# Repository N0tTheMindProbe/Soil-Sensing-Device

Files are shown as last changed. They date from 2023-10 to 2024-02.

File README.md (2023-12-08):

**Overview** 

Welcome to Twin Cities Engineering’s soil gas sensing project. Here, you will find full documentation for both the hardware and software components of our newly developed soil gas sensing device. 

Soil health is a key part within the realm of agriculture and environmental sustainability. As such, understanding the composition of gases within soil void spaces is a powerful means to monitor soil health, offering crucial insights into nutrient content and microorganism activity. Unfortunately, existing commercial soil gas measurement devices are prohibitively expensive, limiting access for farmers and soil scientists alike. To bridge this gap, our team of student engineers is crafting an affordable DIY soil gas sensing device designed to measure carbon dioxide concentrations at three distinct soil depths every 2-3 hours. Our goal is to create a prototype that is not only economical but also portable and user-friendly, increasing accessibility to those wishing to measure and track soil health. 

Our prototype works by collecting gas samples from soil void spaces. This is accomplished with three soil probes of varying lengths (10cm, 20cm, and 50cm) positioned at each of the aforementioned depths. A pump and solenoid valves are used to collect gas samples sequentially from each depth, so they can be passed over a carbon dioxide sensor. A Mayfly microcontroller is used to control each of these functions and record the gas data collected from the sensor. This dynamic setup allows for precise monitoring and data collection, providing a cost-effective and efficient solution for soil health analysis. 

The development of the programming for this device was made possible through the utilization of resources provided by EnviroDIY's ModularSensors repository. The extensive collection of tutorials, libraries, and code documentation available in the ModularSensor repository allowed our team to streamline the programming process and ensure consistent functionality of the soil gas sensing prototype.  

**Quick Start Guide** 

The following is a quick start guide for those wishing to assemble their own soil sensing device. 

Prerequisites: 

Creating a replicated version of our soil sensing prototype does not require extensive programming expertise, making it accessible to those with minimal prior knowledge. However, having the right Integrated Development Environment (IDE) is crucial for compiling and uploading the necessary code to the microcontroller. We highly recommend using VScode with the PlatformIO extension for this purpose. The code for this device relies on numerous libraries from EnviroDIY’s ModularSensor repository, Adafruit, as well as locally sourced ones. The PlatformIO extension conveniently manages and sources all these libraries, saving individuals from having to manage all these libraries themselves. For this reason, we strongly advise using this configuration over simpler compilers like the Arduino IDE. 

Both VSCode and PlatformIO are free to install and run on both Windows and Mac. A detailed tutorial by EnviroDIY on how to download and configure these tools for our project can be found here. 

**Hardware requirements:** 

We selected the Mayfly Data Logger as the microcontroller for this project. Designed by the EnviroDIY community, the Mayfly microcontroller was specifically tailored with environmental data monitoring in mind. For additional hardware specifications and purchasing links, please refer to the EnviroDIY website. 

**Software dependencies/Installation instructions:** 

To install the software for the Mayfly controller, download the ZIP file for the project and open it using PlatformIO. With the project opened, the workstation in VSCode should look similar to this: 



In the examples folder, there are a variety of individual files for each of the main mechanisms of the sensor. These can be ignored, unless individual testing/calibration of components is required.  

To upload the code to the Mayfly device, ensure the connection between the Mayfly and the computer is secure, and that VSCode recognizes the device. Click the checkmark (PlatformIO: Build) located at the bottom left of the screen. VSCode may take several seconds to install and compile each of the libraries required for the prototype to run. Afterwards, the terminal should show a “success” message.  

Clicking the arrow button to the right of the compile checkmark will upload the code to the Mayfly device. Again, this can take up to a minute to complete. Once the code has been successfully uploaded to the Mayfly device, further testing in the Serial Monitor can be done to ensure that the prototype is working as expected. Otherwise, the Mayfly can be unplugged from the computer and installed into the device.   

**Hardware Components** 

Detailed documentation regarding complete hardware assembly (such as component lists, electrical schematics, and pin configurations for the Mayfly) will be located in the docs folder as it becomes available.  

**Software Architecture** 

The general process for the prototype’s programming is shown in the following diagram.  

Screenshot 2023-12-08 at 5 53 21 AM

There are numerous libraries referenced within the main code file that are required to operate the soil sensing device. Several libraries, such as the sensor libraries required for the gas and temperature sensors, are sourced from EnviroDIY’s ModularSensors. There are also a few local libraries, such as the “CollectSample.h”, which is required for operating the pump and solenoids to collect gas samples from the correct depths. All of these libraries work together in the main programming code to effectively operate the prototype.  

**Calibration Procedures for the Alphasense IRC-A1 Sensor** 

The Alphasense IRC-A1 sensor is the sensor utilized in this prototype for collecting carbon dioxide readings from the soil. This sensor comes pre-calibrated by the manufacturer and are generally ready for use immediately after purchase.  

The manufacturers recommend recalibrating the sensor no less than every 12 months to maintain the highest level of accuracy. Further information on sensor calibration procedures can be found on Alphasense’s website.   

**Troubleshooting** 

Output is “nullnullnull...” 

-Adjust the monitor_speed set in the platform.io file 

-Ensure the connection between the Mayfly and computer is secure (no faults in the cable, etc.) 

Output is coming at –9999 or Device only outputs –1250ppm or Readings are very low and/or negative: 

-Ensure that connection between Mayfly and sensor is correct 

-Ensure enough power is being fed to the CO2 sensor (It needs a minimum of 12 volts) 

-If the above solutions do not amend the issue, unplug the CO2 sensor from power for at least 30 seconds, and then plug it back in.  

“Avrdude” connection error: 

-Restart your computer/VSCode workstation.  

-Ensure the USB-C cord is undamaged.   

**License**  

Our soil sensing device project is released under the BSD 3-Clause License, a permissive open-source license that allows for the redistribution and modification of the source and binary forms of the software. This license provides flexibility for users to adapt and incorporate our technology into various applications, both commercial and non-commercial, while still maintaining certain conditions such as attribution and the inclusion of the original license terms. The BSD 3-Clause License aligns with our commitment to fostering collaboration and innovation in the field of soil sensing. 

**Third-Party Licenses** 

In the development of our project, we have incorporated specific third-party libraries, each governed by its respective license. These third-party components contribute essential functionality to our soil sensing device. We adhere to the terms and conditions outlined in the licenses of these libraries or components, and users are encouraged to review the individual licenses for detailed information. This transparent approach ensures that our project not only benefits from external contributions but also upholds the principles of open collaboration and proper attribution within the broader open-source community. 

**Acknowledgments** 

We would like to extend gratitude to the EnviroDIY community for their invaluable resources that have been instrumental to our team's success throughout the semester. The utilization of the ModularSensors repository proved to be vital for creating the programming for this project, serving as a vital resource that significantly contributed to our accomplishments. 

We would also like to thank Anthony Aufdenkampe for his guidance and the contributions he provided for this project. 

EnviroDIY’s ModularSensors libraries are provided “as-is” under the BSD-3 license. Full licensing/terms of use details can be found in the ModularSensors repository here.

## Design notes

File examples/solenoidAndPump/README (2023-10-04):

This is the code that isolates the solenoid values and pump processes.

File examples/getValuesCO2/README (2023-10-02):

#this is the isolated code for the CO2 Sensor's functionality

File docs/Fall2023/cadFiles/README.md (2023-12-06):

#3D print files created by the Fall 2023 team

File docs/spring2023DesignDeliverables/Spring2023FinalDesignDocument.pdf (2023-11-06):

Final Design Document

Twin Cities Engineering

Project Team Students: David Schaeppi, Samuel Day, Kevin Lee, Brendan Dykes, and Jeodaun Lee

Spring 2023 Semester

May 5th, 2023

## Contents

## Introduction

A revolution of farmers interested in smart regenerative agricultural practices has blossomed over recent years. Many farmers of these communities are actively seeking stem tools to help monitor soil health and provide feedback to farmers on the quality of their practice. One method to measure soil health is to measure the gases within the soil. Measuring certain gases in soil provides information about the nutrients and microorganism activity within the soil. Commercially available soil pore space gas instruments are costly, with the cheapest systems costing around $100,000. The high costs leave a demand for a low budget system capable of extracting, measuring, and reporting soil gas concentrations.

To address this issue, a team of engineering students from Twin Cities Engineering at the University of Minnesota, Mankato, is planning to develop a low-cost DIY soil sensing unit. The unit will be designed to extract soil gases from four different depths, providing farmers with valuable information about their soil health. The team plans to make all the information about the project available on GitHub, an open-source platform for software development, so that other farmers and researchers can benefit from their work. By developing a low-cost soil sensing unit, the team hopes to make it easier for farmers to adopt smart regenerative agricultural practices and improve the sustainability of their farming operations.

The DIY soil sensing unit will consist of a gas sampling chamber, a vacuum pump, and an electronic sensor for detecting the gases. The team plans to use off-the-shelf components wherever possible to keep the costs low. They are also exploring the use of 3D printing technology to produce some of the components. The device will be powered by a rechargeable battery, which will be recharged with solar power, making it easy to use in the field.

In addition to providing farmers with information about their soil health, the team hopes that their project will also help to raise awareness about the importance of soil health and the role of regenerative agricultural practices in promoting sustainable agriculture. By sharing their work on GitHub, they aim to inspire others to develop similar low-cost solutions and contribute to the growing community of farmers interested in regenerative agriculture.

Current State of the Art

There are a few longstanding methods of acquiring this data from under the soil, one being gas chromatography. This is done in a large lab space where samples of the trapped gas or soil sample are brough to the lab and examined in these large machines. The chromatography machine is, bulky, high-energy cost and high dollar cost. The next champion in this segment is the FTIR.

Fourier Transform Infrared (FTIR) spectroscopy is a powerful analytical technique that can be used to analyze the composition of specific gases in soil vapor. The technique involves measuring the absorption of infrared radiation by a sample and then using this information to determine the types and amounts of molecules present in the sample.

FTIR spectroscopy works by passing infrared radiation through a sample, such as soil vapor, and measuring the amount of radiation absorbed by the sample at specific wavelengths. Different molecules absorb radiation at different wavelengths, and the resulting spectra can be used to identify the types and amounts of molecules present in the sample.

When applied to soil vapor, FTIR spectroscopy can be used to identify and quantify the concentrations of various gases, such as carbon dioxide, methane, and nitrous oxide. These gases are important indicators of soil health and can provide valuable information about soil microbial activity, nutrient cycling, and greenhouse gas emissions. So the FTIR is a force. However, this is an industry machine that costs in 100k range and requires a great deal of power. More power than we could get out of a 2ftx2ft solar array

What is the Device:

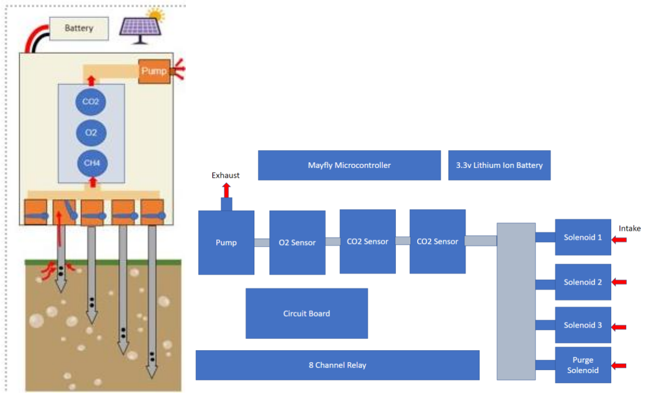
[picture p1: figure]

The images above are diagrams of the system we received from the previous team.

The Device a machine that will stay outside all growing season, it will use a solar panel to charge its batteries. It will be able to accurate a pump to draw gas from under the soil from 4 different depths, run that gas over our sensors and record the concertation of Co2, O2, and CH4. After the reading has been taken, the gas is removed from the chamber via that same pump and ejected through a port in the top of the machine. The data is then saved to an SD card as well as relevant information about Time, Date. Temperature, and Humidity.

## Project Tutorial

### Project Timeline

- Spring 2022
- Developed groundwork for entire soil sensing unit design
- Setup a pump, 8 channel relay and sensor hookup
- Fall 2022

- Created Sensor caps to connect sensors together
- Extracted readouts from sensors
- Programmed framework for device operation
- Data storage on SD card
- Eliminated solenoid noise triggering relay issue using snubbers
- Attempted to implement a methane sensor but fried it
- Spring 2023
- Created a sensor chamber included with temperature control
- Created a prototype bulk water removal system
- Fully implemented entire design into a box for total mobility
- Implemented a low-cost methane sensor
- Properly extract gas from probes
- Completed a GitHub Repository

### Device Design

Design Intent
The soil gas sensor device is designed to provide accurate and precise measurements of gas concentrations in soil. It consists of four soil probes of varying lengths (0.25, 0.5, 0.75, and 1 meter) that can be easily attached to the device. Each probe is equipped with holes to extract gas from the soil when a connected pump is activated.

To ensure accurate readings, the four probes are placed in a 1-meter squared area of soil, under the assumption that soil gas concentrations will not vary significantly within this area. The device itself has four ports to connect tubes from the probes to the device. Each port is connected to a solenoid valve inside the device, which can open and close based on the response from a Mayfly microcontroller.

To ensure precise measurements, the device allows for the exposure of one probe at a time while keeping all other valves closed. This process allows the device to accurately measure the gas concentration at each depth, providing valuable insights into the microbial activity and nutrient levels of the soil. By allowing for the measurement of gas concentrations at varying depths, farmers can make informed decisions about the timing and amount of fertilizer application, thus optimizing crop yields while reducing the use of potentially harmful fertilizers.

Behind the solenoids lies the sensor chamber. The sensor chamber houses an Alphasense IRC-AT carbon dioxide sensor, Alphasense O2-A3 oxygen sensor, a TGS2611-E00 methane sensor, a bme280 temperature, pressure, humidity sensor, and a heating element. The heating element is implemented due to our project team’s worry of condensation forming within the sensor chamber and damaging the sensors. The heating element is connected to an H-Bridge and begins heating if dew point is measured from the bme280.

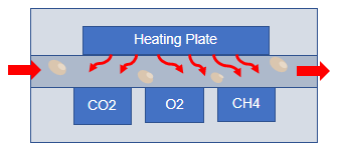
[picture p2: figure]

Figure 1

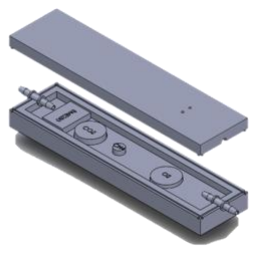
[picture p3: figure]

Figure 2

The Alphasense sensors were chosen due to professor suggestion in the reliability of the brand. Each Alphasense sensor is powered with 12V. To measure the sensors a load resistor of 230 ohms is used for both sensors. The voltage drop across the resistor is measured using an Analog Digital Converter (ADC) to read oxygen and carbon dioxide. The Alphasense IRC-AT has two signal wires. Sig+ connects to one end of the resistor while Sig- connects to the other end. The Alphasense O2-A3 however connects in series. 12 volts powers the O2-A3. The output current is an ADC measurable current of 4-20 mA. The load resistor is placed in series with the O2-A3 sensor for the ADC to measure the voltage drop.

The TGS2611-E00 was chosen due to its low cost and abundant literature claiming the sensor to be a capable low-cost sensor for methane detection. Our team lacks the ability to perform proper laboratory calibrations. Our team assumed we could use equations derived from literature [1] [2], to tune an algorithm to compute relatively accurate ppm readings from measured voltage drop across a load resistor. Our assumptions were wrong.

To compute the TGS2611-E00, ohms law is used to measure the resistance inside the methane sensor. The equation displayed in Equation 1Error! Reference source not found. is used to compute sensor resistance Rs
. For context the sensors circuitry is displayed in Figure 3. The Mayfly ADC measures voltage drop (Vout) across the load resistor Rl

Rs = RL (

Vc

Vout

− 1)
Equation 1

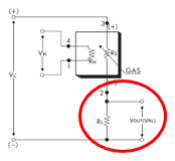
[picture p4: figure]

Figure 3: TGS2611-E00 Sensor Circuit

To convert the ADC’s measured voltage to methane parts per million our team attempted to use equations from Van den Bossche et al [1]. In their paper, Equation (11) converts sensor resistance to methane ppm using a value R0 and measured Rs displayed in Equation 1. R0 is the sensor’s resistance value at a reference point concentration of methane ppm. We recorded R0 in an ambient setting to be equal to 23,250 Ω. Our team recognized we had no way to control environmental factors such as temperature and relative humidity, but we could reference them using measurements from the BME280. When using the equation, we found the trend to compute confusing results. The equation also did not compute an expected trend.

The BME280 was chosen due to its ease of installation. The device has two total BME280s installed with addresses (0x76) and (0x77). (0x76) measures ambient temperature, pressure, and relative humidity within the container of the device. (0x77) measures temperature, pressure, and relative humidity within the sensor chamber. Both the BME280s are used to compare the difference between the ambient environment and inside the sensor chamber. If the temperature is excessively cold out, condensation could occur. Thus, the mayfly continually monitors the temperature and relative humidity inside the sensor chamber to acknowledge when to turn on the heating element.

Device’s Program Flowchart
Shown in Figure 4, the Mayfly microcontroller first reads if any of the bme280 sensors or the external ADC is properly connected. If any of the components are not connected, then the device will not operate. If all components are connected the code will reach Arduino’s loop function. Inside the loop function is a for loop intent on opening one solenoid valve out of four, pumping gas from the solenoid through the device, measuring data, heating the sensor chamber if necessary, and storing the data on a SD card located on the microcontroller itself.

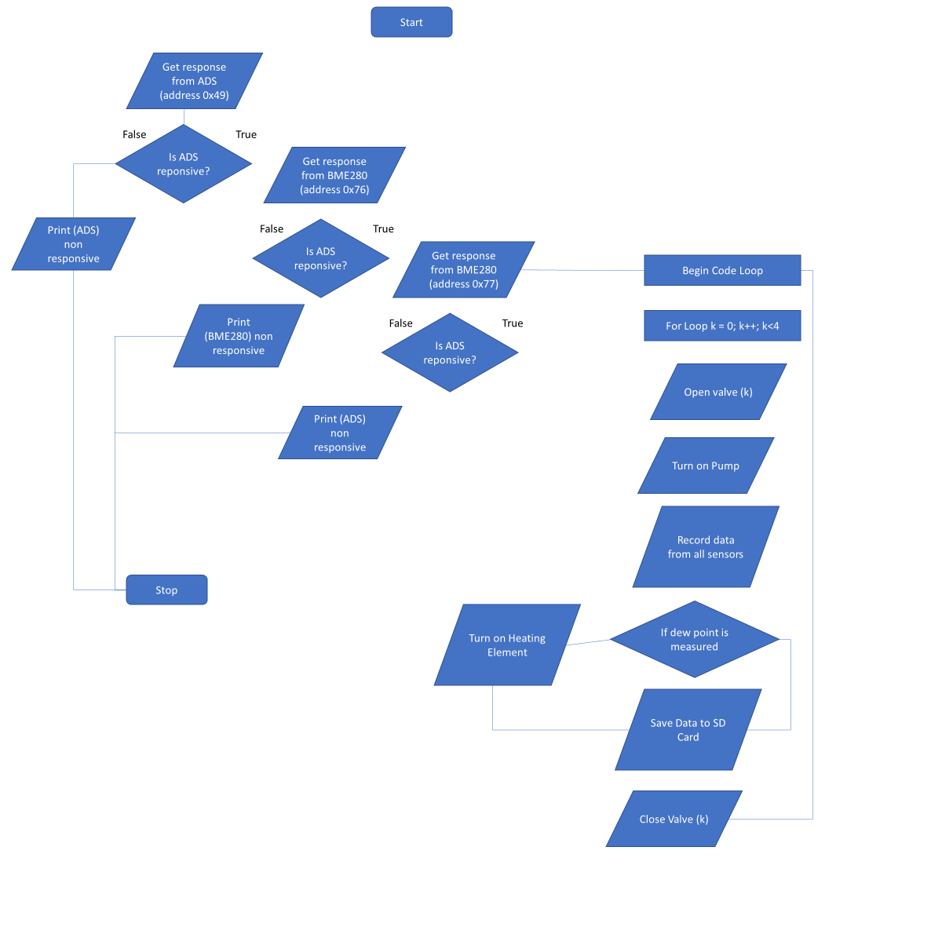
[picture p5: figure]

Figure 4: Program Flowchart

Device Electrical Schematic
The electrical schematic displayed in Figure 5 shows all electrical components wired in the device. At the center of it all, a Mayfly v1.1 microcontroller controls all the operations of the device. Both the Alphasense O2-A3 and the Alphasense IRC-AT voltage readouts are measured using an onboard ADC. An external ADC component, the ADS1115 measures the voltage level of the battery, and measured voltage drop across the load resistor of the TGS2611-E00 methane sensor. The solenoids are controlled with an 8 Channel Relay. Each solenoid is connected to the normally open position. Connected in parallel with each solenoid is a resistor and capacitor in series. These are snubbers intended to dampen AC noise generated when the solenoids are opened or closed. Our project team had a significant problem controlling the relays until the snubbers were installed. To control the pump and heating element, an L298N H-Bridge was used. The H-Bridge can limit voltage supply to the components used Pulse Width Modulation (PWM) from the Mayfly microcontroller.

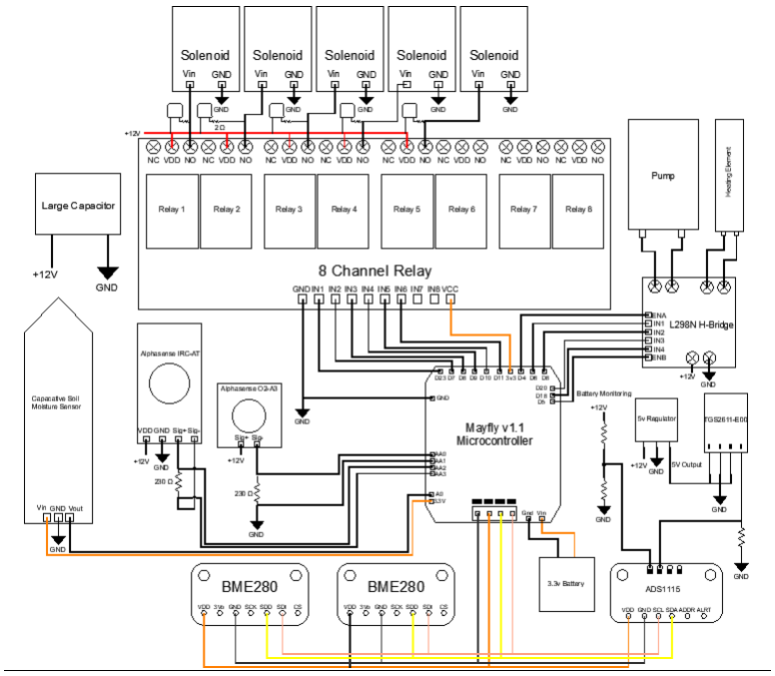
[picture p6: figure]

Figure 5: Electrical Schematic

The Mayfly Microcontroller was chosen due to its capabilities and the microcontrollers focus on being used to monitor environmental conditions in a DIY environment. The EnviroDIY community is behind this device. The Mayfly Microcontroller is based on Arduino and uses the Arduino IDE software for programming. The microcontroller is pivotal for our device because of its range of capabilities. The device uses I2C communication, Analog Digital Converters (ADC), pulse width modulation, and one of the most important points is the number of available pins. In total our device requires 23 individual pins to operate the device leaving the mayfly as a great option.

The solenoids are powered using 12V and controlled from the 8 Channel Relay. Placing the snubbers in parallel with the solenoids is important due to noise generated from the opening and closing of a relay. The noise generated would retrigger the relay even though there was no input. The relay would begin to spasm uncontrollably until the power was turned off. The snubbers absorb AC signal noise and prevent a commonly known issue of the relays going haywire. The solenoids themselves consume a lot of power, about 600 mA per solenoid. The solenoids have been used in all three semesters of this project because the solenoids met the need for testing and designing. All project teams were focused on function and not worried about power consumption.

The L298N H-Bridge is used to control the current supplied to both the pump and heating element using PWM from the Mayfly microcontroller. Both the pump and heating supply are wired to the same H-Bridge but are separately controlled to meet the necessary power consumption. In software the pump is operated at maximum speed to fill the sensor chamber as quickly as possible. For the heating element, about 2 volts was enough to heat the sensor chamber adequately but can be adjusted in the code to either increase or decrease heat output.

The ADS1115 is an Analog Digital Converter (ADC) used to measure the voltage at different points in a circuit. The Mayfly has four onboard ADC pins. Our team is using all four pins to measure the voltage drop across the load resistors of the carbon dioxide and oxygen sensor. Other components we need to measure are the TGS2611 – E00 methane sensor, and the battery voltage. Since our device is planned to eventually be powered by a solar panel, a battery monitoring system has been implemented. The ADS1115 measures from 0 – 5V, but we have it measuring up to 3.3V max due to a warning in the component’s documents. A 100,000-ohm resistor is placed in series with a 10,000-ohm resistor. Using the voltage divider equation and measuring the voltage drop across the 10,000-ohm resistor, the ADS1115 can safely measure voltage and the Mayfly can compute the total voltage supplied by the battery. Lastly the ADS1115 also measures the voltage drop of the TGS2611 - E00’s load resistor and an algorithm are used to convert and compute methane ppm.

The Capacitive soil moisture sensor is used to detect water inside the bulk water removal trap. The Mayfly measures voltage from an analog pin. Currently the program has not implemented any response to water level besides taking measurements. We suggest using measurements from the soil moisture sensor to operate designed water trap.

Water Trap
We chose to use the method of 3D printing to create a water removal unit for the soil project. Full well understanding two things that this method will be able to get a basic design or best shape but the difficult learning curve of the solid works software as this semester is the first time we have engaged with that software.

We started this off by disassembling a commercial water filter, the intent was to use a portion of this, and just print a coalescing tray that we could attach an actuated removal of the water. We took all the measurements of the parts we intended to replace.

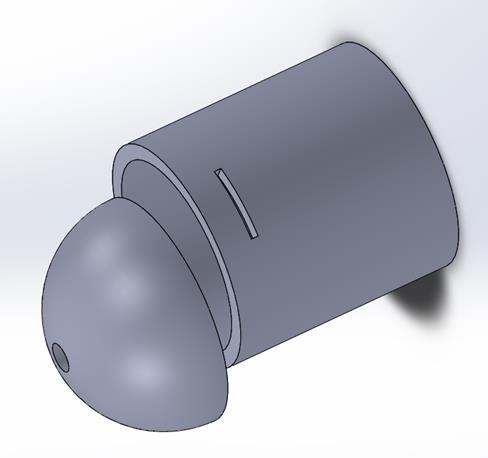
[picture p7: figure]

Figure 6: Screen capture from SOLIDWORKS of the first iteration

The plan at this point was to attach this to a commercial object that had a similarly shaped plastic container over a filter. Our design included a hole in the bottom of the dome, here we would attach the connection to the pump for the water removal. On the side of the Cylinder there is an area for the sensor to communicate the water height has reached its limit, stopping pumping gas in.

It was at this point that we realized the cost saving in just modeling and printing the whole thing ourselves. The whole unit could be assembled ourselves for ~$6.00 of PLA and $10.00 for off the shelf coalescing filter. The commercial filter was currently around $100.00.

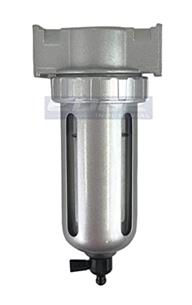
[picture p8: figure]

Figure 7: Example of the water trap (not the exact one) *image from Amazon.com MID FLOW PARTICULATE FILTER/WATER TRAP

printing the top portion came with new learning challenges. The first models are just the basic shapes and I couldn’t even figure out how to make one shape on another without making then separate parts.

The new design was going to incorporate two ports that connect to the hoses using the current iteration of the soil sensor prototype. One the intake port will be in the middle above the coalescing filter and the second will to the side of that this will be the exit port for the air now free of liquid water (at current temp).

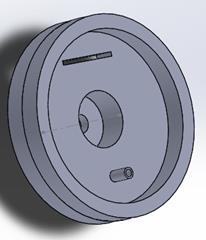
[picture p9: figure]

Figure 8: Screen captures from SOLIDWORKS; Figure is the underside the part.

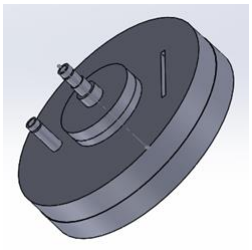
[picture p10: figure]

Figure 9: Screen captures from SOLIDWORKS; Figure is the top of the part.

At this point the plan was the inner walls around the center hole much thicker than the program would have had them as well as made the hole undersized for current purposes. The intent was to bore the proper threads in. A port was added to the top since now we could mount that water level sensor in the top.

The first prints suffered from my not building a design that print easy the large gaps of “ceilings” that this design had a high percentage of failure on the first layers trying to bridge those gaps. This more or less self-corrected after the first layer and the choice to make all the walls slightly thicker for water-tight consideration came in clutch.

Also on the second print the failure in the first layer tipped the interior outlet port over and failed to connect properly. After a few more iterations and the realization that the boring technique that was previously mention was not well understood and we then chose to try to print the threads to attach to the commercial filter

We took all the appropriate measurements of the threads: .771in Diameter of the connector with the threads .767in Diameter without threads (thread width was ~.004in), the connector was .28-inch-tall and displayed roughly 4.1 turns of the threads.

Using this data and the tools on SOLIDWORKS I was able to resize the whole to proper size and add the threading necessary to connect to the filter.

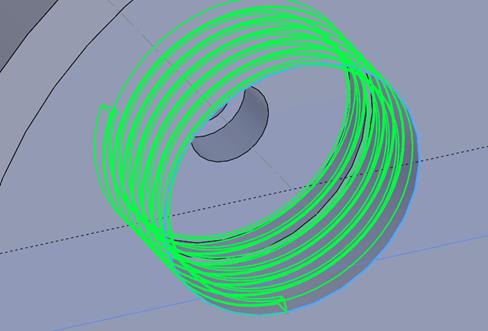
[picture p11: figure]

Figure 10: Screen captures from SOLIDWORKS the thread tool set to 16 thread per inch with .004 thick threads.

The Hosing connections were more just by trial and error (the inner diam of the tubing is not what you want if you want a good seal). During these last iterations I sized up the fittings on the top as well to create a nice seal and added a few ridges to them to help secure and prevent leakage.

Though this design technical works and worked for our demonstration, there is still need for iteration. A large flaw in the current design is that all the OD specs where create to allow attachment to another device we are no longer using. The greater the volume within the chamber the more water can be trapped before the machine will turn off (the more data it can gather) however the greater the volume of the trap the greater the volume of the whole system a system that. The added volume accounts for 80ml of air and needed to be flushed out with 3 times that volume. To guaranty with even a 95% accuracy that we can say “we know where the gas came from”.

So, in future iterations I will need to run simulations on the air flow, with the goal of reducing the volume in the chamber while still allowing for an acceptable amount of water to build before the machine has to turn off and purge the trap.

The 3D printing process has proven to be a great choice for prototyping and developing the water removal unit. This is because 3D printing enables fast production of parts, allowing for multiple iterations and testing of designs with minimal costs. As described in the methods section, the top and bottom parts of the unit required several iterations to optimize their design and ensure they meet the requirements for the project. The ability to make rapid design changes and improvements allowed us to achieve a functional unit that performs well in collecting water from gas drawn from under the soil.

This process was done over about a weeks’ time, if I had tried to get this injection molded or vacuum formed, not only would it have costed hundreds if not thousands for the proper mold to be fashioned to create my part. It would have taken weeks to get those molds made. Each iteration the same costs and time would apply…perhaps for a larger print run of the final iteration that way would could insure that the final iteration would be air and water-tight. Until then 3d printing is the best option.

Calibration protocol
We designed a method for cheap calibrations last semester and even though the hand make calibration gas was within +/- 4% the amount of gas created was 100ml each time. For our calibrations this semester we intended to use a more established method.

The process of making calibration gas using flow meters typically involves the following steps:

1. Select the appropriate gas mixture: The first step in making calibration gas is to select the appropriate gas mixture that matches the gas you want to calibrate. This is usually done by consulting the specifications or requirements of the instrument or sensor being calibrated.
2. Assemble the equipment: Once the gas mixture has been selected, the next step is to assemble the equipment needed for the calibration process. This typically includes a gas cylinder or source, a pressure regulator, flow meters, tubing, and a gas mixing chamber.
3. Set the flow rates: The next step is to set the flow rates of the individual gases using the flow meters. This is typically done by adjusting the flow control valves on each flow meter to the desired flow rate. The flow rates are typically specified in the instrument or sensor calibration documentation.
4. Mix the gases: Once the flow rates have been set, the individual gases are then mixed in the gas mixing chamber. The mixing chamber is typically designed to ensure that the gases are thoroughly mixed to achieve the desired gas mixture.
5. Verify the gas mixture: Once the gases have been mixed, it is important to verify the gas mixture to ensure that it matches the specifications of the instrument or sensor being calibrated. This is typically done using a gas analyzer or other measurement equipment.

It is important to note that the specific process for making calibration gas using flow meters can vary depending on the specific instrument or sensor being calibrated and the gas mixture being used. It is also important to follow proper safety procedures when working with gas cylinders and other equipment to prevent accidents or injuries.

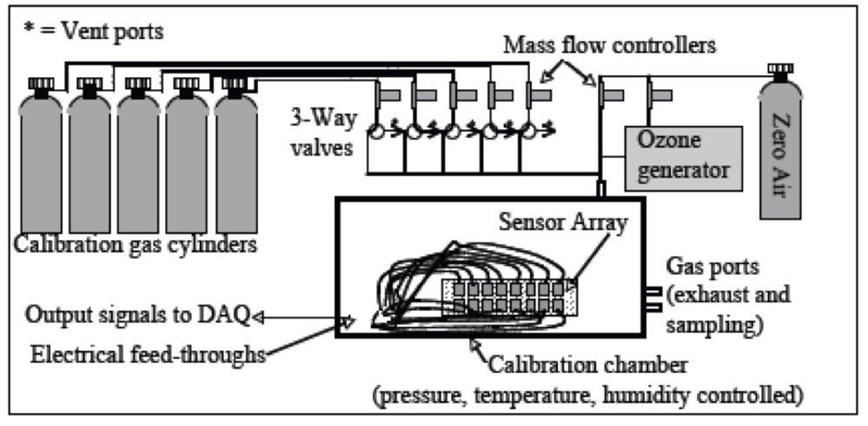
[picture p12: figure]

Figure 11: Calibration Setup Diagram

The Mass flow controllers are between $1500-$2000 a piece and the current layout has at least 4 of them. The good new TCE has many of these flow controllers! However, we did have any of the wires, instructions, or “Controllers” that allow humans to interface with the flow controllers.

We did a good deal of research, found all the instructions, and concluded that this set up would not only cost 2 weeks' time to assemble but that the setup was so cumbersome that few people that would be interested in this DIY project would have the aptitude or resources to invest with this set up.

Because of these set back and realizations we rescoped and went back to the 3-point tests for calibration using the method from last semester using this we got our methane senor calibrated and created an algorithm for turning the output from the sensor to a PPM scale.

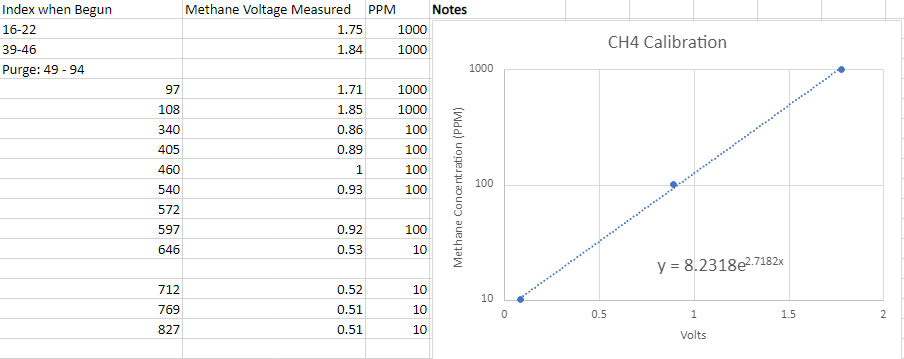
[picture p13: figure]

Last semester’s (Fall 2022) calibration method is attached as an appendix(i)

Motivations
The health of soil plays a crucial role in the success of agricultural production, and farmers can improve crop yields and reduce the use of fertilizers by understanding the level of microbial activity in the soil. Soil gas sensors are useful in this regard as they can detect methane or carbon dioxide which are byproducts of microbial decomposition, an essential process in the soil nutrient cycle. The concentration of these gases provides information about the level of microbial activity and the rate of decomposition, which helps farmers make informed decisions about the timing and amount of fertilizer application.

The use of soil gas sensors enables farmers to reduce their dependence on expensive and potentially harmful fertilizers by applying them only, when necessary, thus reducing the environmental impact of agriculture. Furthermore, optimizing fertilizer use promotes soil health and leads to increased crop yields, ultimately contributing to improved food security.

## Results

Our team attempted to perform experimentation on our soil sensing unit while it was operating. We found during calibration; we could not achieve accurate repeatable values with the installation of the new sensor chamber. Our team also desired to test gas extraction from soil, but since we failed to calibrate properly, we did not investigate the functionality of gas extraction from soil.

## Discussion

### Challenges and Solutions

Mayfly Microcontroller Driver Issue
Our team faced a problem with the Mayfly Microcontroller near the end of the semester. In some way shape and form the on-board ADC stopped operating as expected. Only a week later the USB connector on the mayfly suddenly felt loose and would not snap in as normal. The problems prevented us from uploading new code or reading measurements from the current Mayfly installed in our system. Luckily, we have backup Mayfly Microcontrollers, but we were unable to get use out of them. We found while attempting to upload a program on the different Mayflies, an error “stk500_recv(): programmer is not responding” would repletely display in the output terminal of the Arduino IDE if verbose was turned on in IDE settings. Tracing the error on forums, our team found the issue was likely related to FTDI drivers needing to be installed. However, in our attempt to install the drivers the issue persisted. Our team can only assume we installed the drivers incorrectly. Since our semester is ending, the new semester will have to solve this issue to get the soil sensing device operational again.

Calibration problems
Calibration of methane sensors involves adjusting the sensor's output to match the expected readings for a given concentration of methane gas. This process typically involves the use of specialized equipment, such as gas mixers and calibration standards, which can be costly. In this case, the team decided not to proceed with the calibration because of the cost involved. This decision may have been based on a variety of factors, such as budget constraints, competing priorities, or a belief that the sensor would still perform inadequately. It's worth noting that the decision not to proceed with the calibration of the methane sensor can have consequences beyond just the cost involved. Failing to calibrate the sensor can lead to inaccurate readings.

Use of sintered steel probes
Sintered steel is a type of porous metal material that is commonly used in filtration applications where it is necessary to block particulate matter while allowing gases or fluids to pass through. In the context of soil gas sampling, sintered steel can be used to create a course filter that prevents soil particles and other debris from entering the metal probe while still allowing gas from beneath the soil to pass through.

The sintered steel filter is typically located at the tip of the metal probe and acts as a barrier that prevents soil particles and other debris from entering the probe. The filter is composed of a network of interconnected pores that are small enough to block particles but large enough to allow gas to pass through. This ensures that only clean gas from the soil is sampled, without any contamination from soil particles or other debris.

The use of sintered steel filters in soil gas sampling is an effective way to ensure that samples are representative of the gas present in the soil without any interference from particulate matter. This is important because particulate matter can alter the composition of soil gas samples, leading to inaccurate readings and incorrect conclusions about soil health or other factors of interest.

When sintered steel filters are welded to a solid steel tube, there is a risk of compromising the overall strength and durability of the probe. Welding can introduce weak points in the probe that may break or deform under pressure or resistance, potentially causing damage to the probe or affecting the accuracy of soil gas measurements.

In some cases, sintered steel filters have been found to break at the weld when they come into contact with great resistance. This can be a serious issue in field applications where probes may encounter resistance due to soil conditions or other factors.

To mitigate the risk of structural failure in soil gas sampling probes, it is important to carefully design and construct probes with the appropriate materials and techniques. This may involve using stronger materials or alternative welding methods to ensure the overall strength and durability of the probe.

Overall, while sintered steel filters offer many benefits for soil gas sampling, it is important to consider the potential downsides of welding them to a solid steel tube. Careful attention should be paid to the overall structural integrity of the probe to ensure accurate and reliable soil gas measurements in the field.

Flowrate loss with current solenoids
During experimentation with our device, we tested our tubing for extracting gas from the solenoids to the sensor chamber and then to the pump. We found a large pressure drop from the solenoids which we believe diminished the device’s gas extraction rate. This semester we do not have the time to replace the solenoids with more efficient ones, so we are left with extracting at a very slow flow rate even with maximum pump rate.

Methane sensor oxygen dependence
One key issue with the current Figaro TS2611-E00 methane sensor is the strong oxygen cross sensitivity. We recognized our sensor will operate in an anoxic (low oxygen) environment. We also expected the TS2611-E00 to have a cross sensitivity to varying oxygen concentrations. We tested the issue using argon to purge the oxygen from the sensor chamber. We did not expect the oxygen cross sensitivity to be many times larger than the humidity and temperature cross sensitivities. This strong oxygen cross sensitivity means the sensor will be least accurate when the methane concentration is potentially high enough for the sensor to measure. This severely limits any possibility of collecting any useful data with the Figaro TS2611-E00 methane sensor in a soil gas sampling application. Two possible solutions are discussed in Future Recommendations.

Device Wire Management
The circuitry of the device was soldered onto a smaller soldering board. When installed our team had a lot of trouble getting access to components inside the box with the circuit’s wires in the way. A new larger soldering board was added, replacing the old one. This soldering board has terminals to allow users to change wires around easily and without hassle. Still the board is large and wires inside the box still do not have much room.

### Future Recommendations

Methane Sensor
In the Challenges and Solutions we discussed the TGS2611-E00’s strong oxygen dependence and how it does not fit our purpose due to the accuracy severely worsening in the target anoxic environments. Our team found a possible replacement, the Cubic brand Gasboard2502 TDLAS methane sensor. The price is $2,300 per sensor with an accuracy of +/-5ppm and a repeatability of +/-1.6ppm. This may not be accurate enough for useful methane measurements in dry soil with methane in the 2-10ppm range, but it will almost certainly have adequate accuracy for anoxic conditions with methane in the 25-100ppm range. The Gasboard2502 sensor will double the device component cost.

No Methane Sensor
The other option is to not include a methane sensor. This allows an attractive alternative design, the “sensors in probe” design. This design almost certainly requires not using a methane sensor. The sensors in probe design eliminates many components, including the air pump, air solenoid valves, air manifold, water valve, water separator, sensor chamber, heater, and plumbing. This leads to advantages in reduced power use, lower design complexity, and fewer points of failure. The main challenge with the sensor in probe design is keeping the liquid water out of the sensors. This is the most likely point of failure. This design may use hydrophobic membrane filters, plugs made from sintered hydrophobic material, or some other method to keep water out (grey sections of exterior shell).

“Sensors in probe” description
The CO2, O2, and temperature humidity combination sensors are removed from their circuit boards and inserted into the soil probe. The sensors are connected remotely to their circuit boards with ribbon cable. Liquid water is prevented from entering with a hydrophobic filter or similar. The hydrophobic filter allows soil gases to diffuse through it. The probe has duplicates of each sensor in separate chambers at each soil depth. The sensors may be assembled onto a frame that in slid into the tube as one piece. A seal of caulk or an O-ring between each set of sensors would prevent soil gas mixing vertically in the tube.

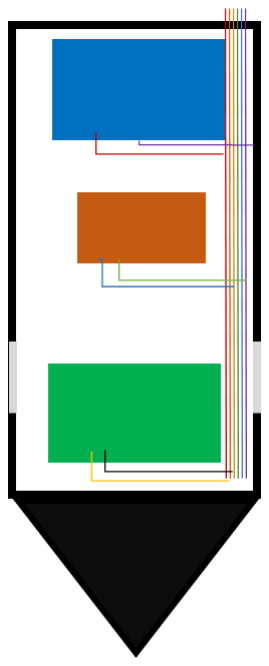
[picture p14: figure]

Sensor in probe design detailed view.

Sensor in probe complete probe layout.

Applying regression to create a calibrated algorithm
Based on the actions from literature, using statistical analysis tools such as regression improves algorithm calibration. We recommend using two-point calibration and linear regression to improve calibration results. Setting up an experiment to calibrate the methane sensor alongside a temperature, humidity sensor could allow better calibration even in environments with changing temperature and humidity. Our recommendations come from work done by Bastviken et al [2].

Design Issues
Currently the sensors installed in the device are connected to the 12V supply or 5V supply without any on or off switch. In the future wire the sensors to connect to relays. Wiring the sensors to a relay could reduce power consumption for a long time simply by turning the sensors on or off when needed. Keeping in mind the sensors do need time to warm up. The sensors warm up in about 30 seconds, but more accurate measurements are possible at 30 minutes. Weighing the cost benefit is necessary if making this change.

Currently, the mayfly microcontroller in the device is supplied by a separate 3.3v battery. In the future, connecting the mayfly to the main power supply would prevent the risk of the mayfly running out of power. Eliminating the 3.3v battery would also eliminate the need for a person to continually replace the battery when servicing the unit. Lastly, eliminating the battery could increase space inside the unit. If necessary, incorporating the 3.3v lithium-ion battery as a backup could be useful. The current design recognizes the method for analyzing supply battery voltage, but no work has been done to implement a stop mechanism for when battery voltage reaches a certain low.

The current installed Solenoids are a problem for the device for three reasons. 1) the current solenoids are bulky and difficult to connect to. 2) The solenoids consume an abundance of power, way more than necessary. 3) The solenoids cause problems with the flow rate of the device. With different solenoids the device may be able to extract gases better, consume less power, and be easier to install. Overall, the solenoids are to expensive in terms of space, and power. Other smaller solenoids exist with much less power consumption making the current solenoids obsolete.

The current sensor chamber and pipe system for delivering gases extracted from probes has problems. The sensor chamber leaks due to being printed from PLA, and its inside volume is much larger than necessary. To resolve these issues, we recommend creating a sensor chamber with a leak-proof material and optimizing its inside volume to maximize gas contact with the sensors. Reducing the sensor
chamber volume will also decrease pumping time and lead to long-term energy savings.

Our team implemented a battery level monitoring system using a voltage divider and a single pin from the ADS1115 ADC. However, we created a new circuit board for the system including terminal screws instead of hardwired soldered connections. The new circuit board lacks the voltage divider created on the previous circuit. Reimplementing the battery monitoring system would be useful. The voltage divider can be seen in Figure 5: Electrical Schematic. When a battery operates, its terminal voltage decreases when losing power. Performing a power drain test with the battery monitoring system will show at what voltage the battery is at low power. The device can then be programmed to perform actions based on low battery voltage.

In the Fall 2022 semester, time readouts were implemented into the Arduino program. In Spring 2023, our team did not focus on time. Slowly the time measurements became inaccurate and unusable as the internal clock drifts. Perhaps time could be adjusted using Fall 2022 program found in the GitHub repository. Our team recommends correcting the time readouts for useful context when datalogging. Instructions should be made for the client to periodically correct the internal clock time.

During this Spring 2023 we found calibration difficult and expensive. To perform proper laboratory calibration requires a lot of resources. Our team found our calibration procedure using a 10 ml syringe to be cost-effective and useful. Despite the absence of advanced laboratory equipment or specialized knowledge, our method has demonstrated efficacy in conserving resources and time. Nevertheless, the project is an open-source DIY resource for people. The syringe calibration method could be useful to the open-source community, but perhaps finding a commercial resource could provide value to next semester’s team and the open-source community.

Gantt Chart for Fall 2023
Our team created a Gantt Chart we expected would be reasonable for next semester’s team. The Gantt Chart includes objectives and tasks already scoped for a team to reasonably finish the objectives by the end of the Fall 2023 semester. However, this is a template and created a lot of value for our team in the Spring 2023 semester. Using a Gantt Chart provides accountability for your team to accomplish tasks in a timely manner. Our team recommends using our Gantt Chart and altering it to accommodate the problems faced during the semester.

## Conclusions

In conclusion, The Spring 2023 soil sensor team focused on developing a low-cost, DIY soil sensing unit that can extract, measure, and report soil gas concentrations from four different depths. This project addresses the high cost of commercially available soil pore space gas instruments, which can hinder farmers' ability to monitor their soil health. The project has been ongoing with Spring 2023 being the third semester of the project. The Spring 2023 team created a prototype sensor chamber and a prototype water trap. Our team was able to implement the sensor chamber into the design and implement program logic to operate the heating element inside the chamber. The water trap design was 3D printed, but unfinished and untested. Our team installed a TGS2611-E00 methane sensor into the soil sensing unit but found and later validated the sensor reacted improperly to anoxic environments. A new circuit board was implemented with screw terminals to improve wire management and improve a user’s ability to change around components. The conversion to a new circuit board eliminated the battery monitoring feature installed on the previous circuit. Our team explored what resources would be necessary for proper calibration of our device and found the resources to be very expensive. Our team stuck with a syringe method because of the low cost and easy applicability. Our team created a Gantt Chart for the Fall 2023 semester for the next team to use as an outline. The Gantt Chart supports a lot of our recommendations for the next team to perform in the future.

## Program and supporting Resources

The program and supporting resources such as STL files, a condensed Final Design Document, Technical Poster, and more information about the project can be found on our GitHub repository with the link provided. https://github.com/TheGreatBuddo/Soil-Sensing-Device.git

## Appendix i - Calibration

This Calibration Protocol will be run using the existing concepts of volumetric measurements and serial dilutions to correctly create our own calibration gas. This step is necessary to confirm the data sheet information and set up our equations to convert the output to proper percentages and ppm. We will do this by passing 100ml of our calibration gas over the sensors. We will first cover the Items necessary for calibration, The warmup time of the sensors, then cover O2 Sensor calibration then the CO2 Sensor, and lastly the CH4 Sensor.

Note: This Method was tested against 2 off the shelf handheld CO2 Stafty sensors, Accuracy of method was withing ±20ppm

The Required Objects

- Blackburn, 16g Threaded CO2 refills
- Blackburn Inflator
- One Tank of Argon, Compressed
- Methane Calibration Gas (1000 ppm, Nitrogen Balance, 17 Liter
- 100ml luer lock plastic syringe
- 10ml luer lock plastic syringe
- 2 male to female luer lock tips .167 in OD (M2F-ll)
- 3-inch section of .25 OD soft plastic tubing
- 0.50-inch section of .25 OD soft plastic tubing
- ~15 Balloons (Container for our gas CO2 and Argon)
- Soil Vapor Device

The first test is the Warmup time of the sensors. In this Test we will set up the system and turn on the pump and the sensors in series, as well as have the mayfly logging the data. Allow the system to run uninterrupted for 1 hour. While the systems are running, all the ports are drawing from the “same” ambient air not placed in the ground. The intent is to look at the data afterwards and find the point at which the values stabilize. Then compare those results to the values on the data sheet.

The first calibration test was performed to check the 0 values on the sensors. This was achieved by venting some gas from the compressed Argon into a balloon for storage. Then the balloon is attached to the top of the 100ml Syringe by pinching 1 inch from the inlet and stretching the remaining balloon over the syringe. Draw 100ml out of the balloon, because of the pressure in the balloon this will affect the size of the balloon less than one would think. Once you have the 100ml pure Argon calibration gas, we will attach the M2F-ll tip to the 3-inch tube and then affix the other end of the tube to the sensors. Attach the syringe to M2F-ll (some of the Argon will expel as the pressure equalizes between the syringe and the ambient air pressure- this is expected and will not affect current process). Turn the power on the pump off. Mark the time for reference and push the 100 ml of gas over the sensors for 10 seconds. Log the data and track the lowest values that are output from the sensors. After 0 value test, reattach the pump to clear the line back to ambient values. Repeat this calibration step 2 more times and use the lowest values. This data will be used as the zero value to detect change. ie: if 1.1v is the 0 value then and the next tested value is 1.3v that is a change of .2v) this will be used later for ppm calculations.

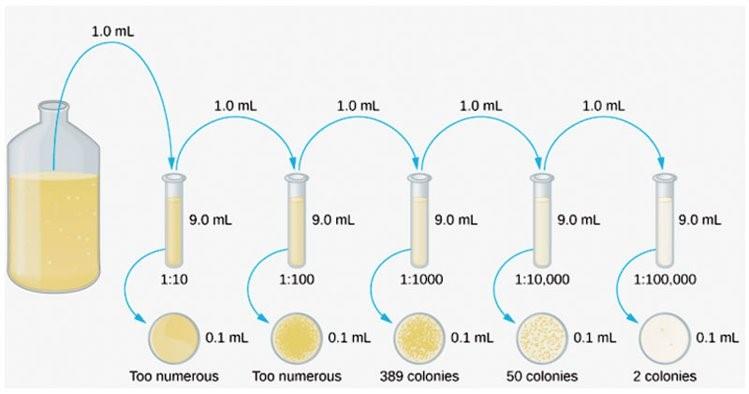
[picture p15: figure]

The second calibration test will be testing the O2 sensor with 5%,10%,15% concentration of O2. Each of these calibration values will be tested 3 times for repeatability and accuracy. To create our calibration gas for O2 we will need to assume that ambient air is ~20.9 O2. Then we can set up the equation y=20.9x where y is the goal for the % of o2 being tested.

Ie: @5%

5=20.9x ⇒ 5/20.9=x ⇒ x= 0.239

So, with this we can convert that into 23.9% of the 100 ml of gas in our syringe.

First Draw 76.1ml of argon from the balloon into your 100ml syringe. Remove the balloon and attach the M2F-ll. At this point the argon will decompress to ambient pressure and you will begin to draw in the remaining 23.9ml of air. This is now a 5% O2 concentration of calibration gas. Turn the pump off and attach the 100ml syringe to the sensors in series and mark the time. Administer the 100ml over a 10 second period. Log the data and then attach the pump again to purge the system with ambient air until normal values return (~20-30 seconds).

The same math and method can be applied to each of the other values:

@10%

10/20.9=x ⇒ x= 0 .478

Thus, start with 52.1 ml Argon and then draw in 47.8 ml of air to creating 10%

@15%

15/20.9=x ⇒ x= 0.718

Here, start with 28.2 ml of Argon and then draw in 71.8 ml of air to create 15%

Note: First iteration of the calibration test used CO2 as the balance gas for the O2 sensor however O2 sensor has a CO2 sensitivity, if the CO2 is above 5% (50,000 ppm) these levels are unexpected in the field use of this device however when exposed to even the lower value of 28% CO2 the sensor itself would output roughly 37% expected amperage.

The Next sensor to calibrate will be CO2. We will use a similar method to the O2 sensor however we will need to employ a process called serial dilution to achieve the smaller required values of 1000 ppm, 2000 ppm, 3000 ppm, 4000 ppm and 5000 ppm. Start out with one balloon of argon gas, and then create a second balloon with CO2 gas. To do this screw one of the 16g threaded CO2 cartridges into the Blackburn Inflator, pull the balloon over the dispenser nozzle and over the back of the dispenser. Pinch around the neck of the inlet again and pull the nozzle back slowly to release some of the CO2 from the cartridge. Once both balloons are ready, then prepare the 0.5-inch soft plastic tube with both M2F-ll tips inserted on either side of the tube (ideally touching inside the tube to reduce contamination) hereafter referred to as “docking tube”. After that, use the 100 ml syringe to draw 95 ml of argon. Then use the 10 ml syringe to draw 5 ml of CO2 out of the other balloon, attach both syringes to the connecting docking tube to draw the 5 ml CO2 into the 100 ml syringe. At this point we have a 5% concentration or 50,000 ppm, allowing time for diffusion (~5-10 second). Now implementing the serial dilution process, if we want to reduce the current concentration by a factor of 10, we can transfer 10 ml of the 5% concentration back to the 10 ml syringe. Then expel the remaining gas in the 100 ml syringe. Next, draw another 90 ml of pure argon from the balloon and reattach it to the docking tube. Return the 10 ml 5% concentration to the 100 ml syringe and now a 0.5% concentration of CO2 or 5000 ppm. Lastly remove the 100 ml syringe and one of the M2F-ll tips to attach to the sensors in series, turn off the pump and mark the time. Administer the gas over the standard 10 second window. Log data, turn the pump back on to clear the line and return to ambient values. Then repeat 2 more times for 5000 ppm. Note: the 5000 ppm should be the max the sensor will detect thus should receive max output.

This same method will be used to get other values

@4000 ppm

Start with the 100 ml syringe with 96 ml of argon and the 10 ml syringe with 4 ml of CO2 attach both to the docking tube draw 4 into 96 and allow time for diffusion. Transfer 10 ml back to the 10 ml syringe @4% concentration then dilute into another 90 ml argon to achieve 4000 ppm

@3000 ppm

Start with the 100 ml syringe with 97 ml of argon and the 10 ml syringe with 3 ml of CO2 attach both to the docking tube draw 3 into 97 and allow time for diffusion. Transfer 10 ml back to the 10 ml syringe @3% concentration then dilute into another 90 ml argon to achieve 3000 ppm

@2000 ppm

Start with the 100 ml syringe with 98 ml of argon and the 10 ml syringe with 2 ml of CO2 attach both to the docking tube draw 2 into 98 and allow time for diffusion. Transfer 10 ml back to the 10 ml syringe @2% concentration then dilute into another 90 ml argon to achieve 2000 ppm

@1000 ppm

Start with the 100 ml syringe with 99 ml of argon and the 10 ml syringe with 1 ml of CO2 attach both to the docking tube draw 1 into 99 and allow time for diffusion. Transfer 10 ml back to the 10 ml syringe @1% concentration then dilute into another 90 ml argon to achieve 1000 ppm

Mark the time of each calibration run and its value being tested for later reference against the logged data.

Lastly The CH4 Sensor calibration will be very similar to the CO2 calibrations we will be using the argon balloon but now we need to create the CH4 gas balloon by attaching the balloon to the value and expelling some gas into the balloon. The CH4 gas is 1000 ppm to start with and the goals are to archive values for 10 ppm, 50 ppm, 100 ppm, & 150 ppm. Using a similar equation to the first calibration y=1000x, where y is our desired ending concentration

@100 ppm

100/1000=x ⇒ x=0.10

Start by Drawing 90 ml of Argon into the 100 ml syringe and then drawing 10 ml CH4 into the 10 ml syringe attach both to the docking tube and transfer the 10 to the 90 to create a 100 ppm concentration.

@75 ppm

75/1000=x ⇒ x= 0.075

Start by Drawing 95 ml of Argon into the 100 ml syringe and then drawing 7.5 ml CH4 into the 10 ml syringe attach both to the docking tube and transfer the 7.5 to the 92.5 to create a 75- ppm concentration.

@50 ppm

50/1000=x ⇒ x= 0.05

Start by Drawing 95 ml of Argon into the 100 ml syringe and then drawing 5 ml CH4 into the 10 ml syringe attach both to the docking tube and transfer the 5 to the 95 to create a 50-ppm concentration

@25 ppm

25/1000=x ⇒ x= 0.025

Start by Drawing 97.5 ml of Argon into the 100 ml syringe and then drawing 2.5 ml CH4 into
the | 10 ml syringe attach both to the docking tube and transfer the 2.5 to the 97.5 to create a
25 | ppm concentration

Note: the CH4 calibration gas is at 1000 ppm or 20% of LEL. This CH4 concentration is not explosive in a normal atmosphere with 20.9% ambient O2 and is within NIOSH (National Institute for Occupational Safety and Health) safety standards for human exposure for up to 8 hours with sufficient ventilation.

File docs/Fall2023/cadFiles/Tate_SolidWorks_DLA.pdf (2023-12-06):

ENGR 452: Adv. Tech Competency: SolidWorks Modeling (005375) Fall 2023 | 1

Project DLA: SolidWorks Independent Study (Soil Sensor Manifold)

Student: Tate Putman | Instructor: Yuezhou Wang
| Due 12/8/23

### JUSTIFICATION

Background Information

It is valuable for an engineering student to learn CAD modeling, specifically SolidWorks, for multiple reasons. CAD modeling is a widely sought-after skill in the engineering industry because it allows for the user to translate an idea or sketch into a three dimensional prototype. SolidWorks specifically is valuable as it is widely considered the industry standard and by far the most widespread CAD modeling software in use. In addition to 3D modeling, it has extensive simulation capabilities including Finite Element Analysis (FEA). Although simulations are not within the scope of this technical elective, it is important to learn the basics of SolidWorks in order to be able to eventually use the simulation aspect of the software to its full capability.

Learning Outcome Justification

The Scope of Work in this specific design was to design and print a manifold that would connect the three solenoid valves as intakes, and lead to a single output going to the gas chamber. The part had to be within certain size constraints, as detailed later in this DLA.
I was the only team member who worked on the design of this part, and therefore all of the work shown in the FDR in this area represents my personal technical learning.
This activity withing the design project meets many of the “student learning outcomes” of this advanced technical competency. Every specific learning outcome in the syllabus is listed below.

A brief description of how the working knowledge of each outcome is shown in this project is then described.
- Sketch Entities
- Sketch Tools
- Sketch Relations
- Boss and Cut Features
- Fillets and Chamfers
- Patterning Tools
- Dimensioning
- Feature Conditions
- Mass Properties and Materials
- Inserting Components
- Standard Mates
- Reference Geometry
- Drawing Basics
The sketch entities are used in the basic sketch of the sweep profile, specifically the elliptical arcs. But all basic components of the sketch are considered entities. Sketch tools such as sketch snaps and “stretching” the sketch were both used in the preliminary sweep sketch as well.

There is a sketch relation ensuring the sweep and the sweep base are perpendicular to each other. Midpoints are selected with dynamic highlighting in the sketch as well.

All of the major components of this part are extruded as a boss feature, and the hollow inside is a cut feature. The circular base is the reference geometry by which the shape of the solid sweep is defined. While extruding the inlet valves, the “up to next” feature condition was used. Fillets are added around the inlet extrusions to increase the robustness of the part and reduce the stress concentration. See below for an illustration of fillets in a scenario similar to this part (Figure 1).

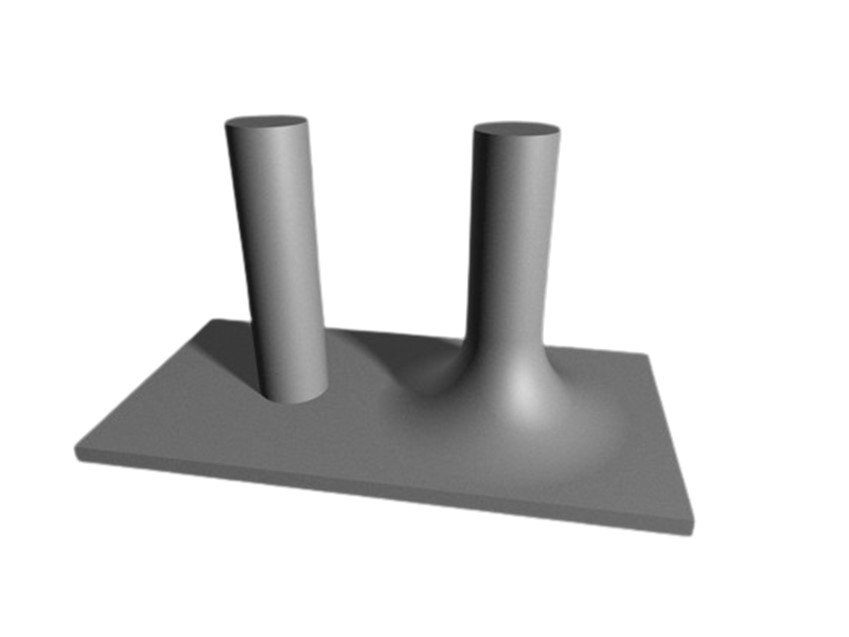
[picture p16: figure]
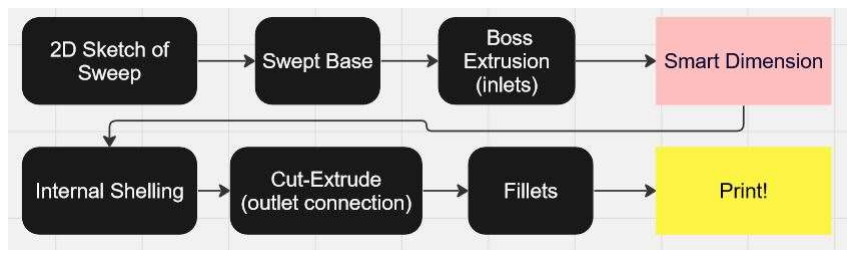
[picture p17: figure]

ENGR 452: Adv. Tech Competency: SolidWorks Modeling (005375) Fall 2023 | 2

Figure 1 – Fillet vs no Fillet[2]

To ensure the part meets the dimension requirements, smart dimensioning was used to define the part and stay within measurement constraints while being edited.

At the end of the document, details of mass and volume are included from the mass properties tool on SolidWorks, and a part drawing is included as well at the end of the document.

As this part is not an assembly, the concepts of standard mates and inserting components are not used. A standard mate is a constraint which defines how parts of an assembly are connected. Inserting components is the process of how each part is added into the assembly. Patterning tools were not used in the creating of this part either, because we did not have a repetitive design. It would have been an ineffective use of time to use a patterning tool to create the two circular bases for the inlet extrusions.

### MAIN BODY (Content from FDR)

(note: this content structure is formatted to look more DLA-like, but the content itself is the same as the FDR)

Design Overview and Constraints
To connect the three airlines from the probes into a single airflow into the gas chamber, a manifold had to be designed. The manifold needed three inlets which fit into the solenoid valves themselves. The outlet outer diameter needs to fit airtight within the tubing. Specific dimensional constraints are in the following section.

A general flow chart of the process of modeling this part is shown in Figure 2.

Figure 2 - Manifold Modeling Flow Chart (miro.com)

Dimensions:

The first step in designing a part such as this is to measure the dimensions of the parts which it will connect to, in this case the solenoid valves as well as the plastic tubing which connects to the gas chamber.

The inner diameter of the plastic tubing measured to be 4.5 mm.

The inner diameter of the solenoid connections measured to be 6.4 mm.

The three solenoid valves are designed to sit side-by-side in the Pelican case. Because the manifold is designed to be a rigid part, the distance between the center of each manifold inlet valve has to equal the distance from the center of each connection point on the solenoids. This measurement was 24.0 mm.

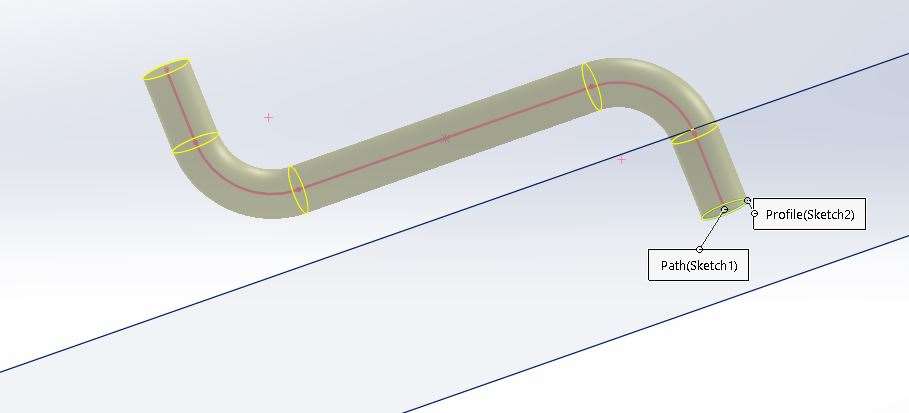
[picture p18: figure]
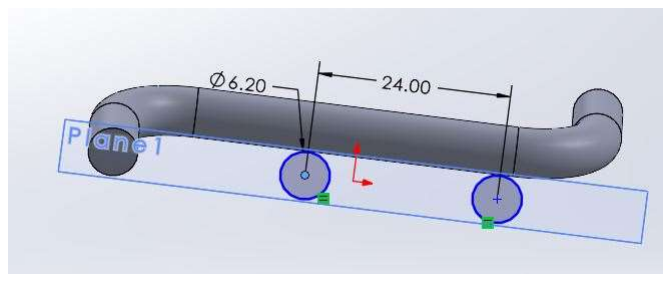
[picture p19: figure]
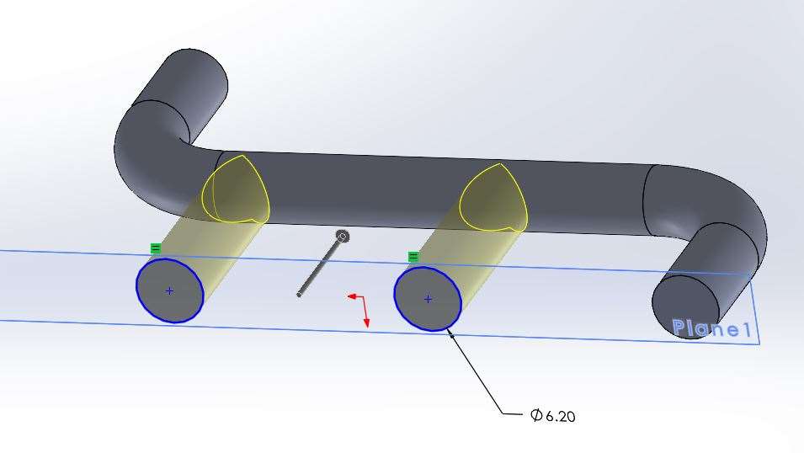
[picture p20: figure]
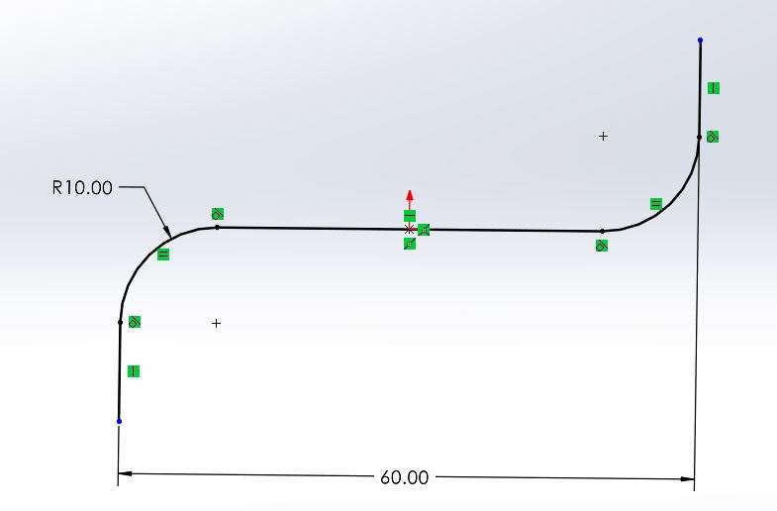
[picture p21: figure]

ENGR 452: Adv. Tech Competency: SolidWorks Modeling (005375) Fall 2023 | 3

The area in which the manifold had to fit within an area of 100.0 mm, but the smaller the length of the manifold the better in order to allow space for other components to fit.

Sketch:

To create this part, a new sketch is created on SolidWorks. First, to make sure all units of measurement are the same, the units are set to metric “MMGS” on the bottom right corner of the screen. The sketch is based off of a reference plane called “Plane 1”, which is parallel to the “Front Plane”.

The first step in the actual sketching of the part is to create a sweep. A profile of the sweep is sketched on the plane, which will represent the outer diameter of the manifold tubing. This is a circle with a diameter of 6.4 mm.

Next, the sweep was created, starting with a perpendicular relation to the profile. The 90° curves with a radius of 10.0 mm are to create a smoothed-out bend to reduce pressure loss in the tube compared to a right-angle. The total length of 60 mm is the minimum length for all of the intakes to be evenly spaced while still being connected to the horizontal part of the sweep. See the sweep in Figure 3 below.

Figure 3 – Sweep

The base is then swept around the “sweep” sketch using the “swept boss/base” tool. This results in the 3-D “skeleton” of the model, shown in Figure 4.

Figure 4 - Swept Base

After this initial skeleton is created, the next step is to extrude what will become the other two inlets. These bases are sketched 24.0 mm apart on Plane 1 and extruded to the main manifold using the “up to next” feature condition in the Boss-Extrude Menu. See Figures 5 and 6.

Figure 5 – Dimensions

Figure 6 – Boss Extrusion

Next, in order to hollow out the manifold structure, the “shell” tool is used. Each circular base is selected except for the top, as the top needs to have a smaller diameter than the others for the tubing to attach. The parameter for “thickness” is set to 1.2 mm. This dimension is chosen due to it being on the “high-end” of the minimum suggested wall thickness for a PLA part[1]. See Figure 7 for a visualization of how the bases were selected and then shelled out.

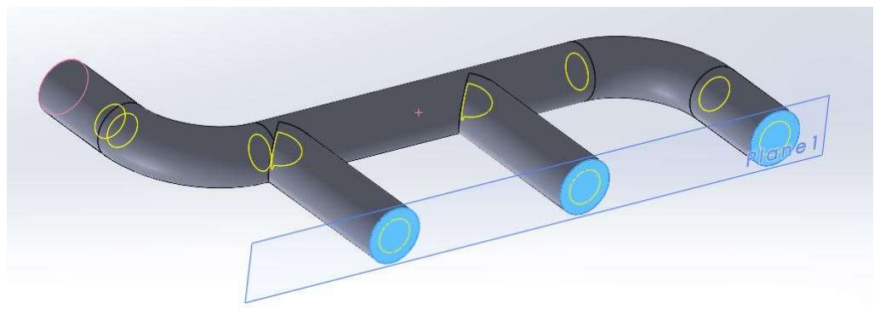
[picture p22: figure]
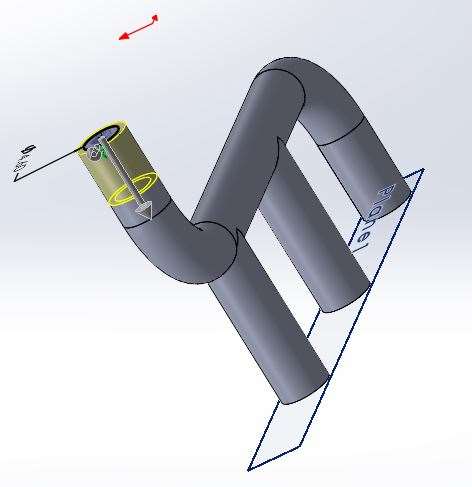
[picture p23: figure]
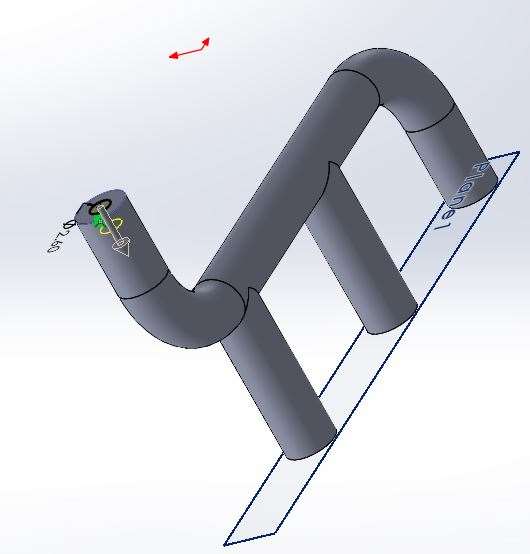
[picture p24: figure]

ENGR 452: Adv. Tech Competency: SolidWorks Modeling (005375) Fall 2023 | 4

Figure 7 - Shell Feature

The final major modification to this part is the outlet, which needs to have a smaller diameter (4.6 mm) to fit inside the plastic tubing. First, 8 mm of material was extruded from the top of the outlet face downward, with a diameter of 2.6 mm. This will act as the inner tube of the outlet through which gas will flow. After this, 7.0 mm of material with an inner diameter of 4.6 mm is also extruded from the top of the outlet face. This results in a outlet connection point with an outer diameter of 4.6 mm and 1.0 mm wall thickness. (The length of this connection was point was changed from 5 mm to 7 mm over three iterations in order to better connect to the tubing.) See Figures 8 and 9 below for the above descried steps.

Figure 8 - Cut-Extrude 1

Figure 9 - Cut-Extrude 2

The final modeing step is to add fillets, which were added after the first print iterations in order to increase durability of the part. (This was not due to part failure, but to follow best design practices.) Fillets distribute the stress over a broader area than the would-be sharp “corners” of where the extrusions meet. The dimensions of the fillets are 2 mm. To add these to the model, click “fillet”, and then click the boundaries to which you would like them to be added. Then, set the radii and click save. The locations of the fillets on the manifold are highlighted in blue on Figure 10 below.

Figure 10 - Fillets

This concludes the modeling portion of the creation of this part. The technical drawing of this part, annotated with smart dimensions, is on the last page of this document. Please see Figure 14.


ENGR 452: Adv. Tech Competency: SolidWorks Modeling (005375) Fall 2023 | 5

Printing Instructions

The .STL file of this manifold is available in the project GitHub. Download this .STL file and upload it to the 3D printer slicing software that corresponds to your printer. The Soil Team uses a Prusa 3D printer, so the file was sliced using PrusaSlicer.

Once the .STL file is uploaded to the slicing software, the first step is to change the print orientation to “upright”, where the three inlet holes are resting on the printer bed (Figure 11).

The print settings should be set to a “Quality” setting (0.15 mm or 0.10 mm are both acceptable). The filament used is a “Generic PLA.” Set the supports to “Support on build plate only” and infill to “80%”. Once the settings are set, it should look similar to Figure 12, depending on your slicing software.

Figure 11 - Printer Bed Orientation (PrusaSlice)

Figure 12 - Print Slicer Settings (PrusaSlice)

If the print settings are set correctly, press “slice now” to export the g-code file that can be uploaded to the printer. Move this file to a storage device that can be inserted into the printer.

Follow the instructions on the printer display to continue to print the part. Default settings were used when the Soil Team printed this part.

Mass Properties & BOM

Although not crucial for the purposes of this project, details relating to the exact mass and volume of material that this part takes up can be found by clicking on the “evaluate” tab, and then “mass properties” in SolidWorks. The manifold that has been created weighs 2.35 grams and uses 2,348 mm³
of material.

Another interesting tool to use in SolidWorks is the Bill of Materials creator. If this project were using a parts assembly, it would be more relevant, but in case it is of interest here is the BOM generated for the single-part manifold (Figure 13).

Figure 13 - Manifold BOM


ENGR 452: Adv. Tech Competency: SolidWorks Modeling (005375) Fall 2023 | 6

SolidWorks Part Drawing

Figure 14 - SolidWorks Drawing--Manifold

Relevant Sources

[1] Wall thickness (3D printing): How to make it perfect. All3DP. (2023, October 13). https://all3dp.com/2/3d-printing-wall-thickness-tutorial/
[2] Fillet (mechanics). (n.d.). Wikipedia--Fillet (mechanics). Retrieved December 1, 2023, from
https://en.wikipedia.org/wiki/Fillet_%28m echanics%29.

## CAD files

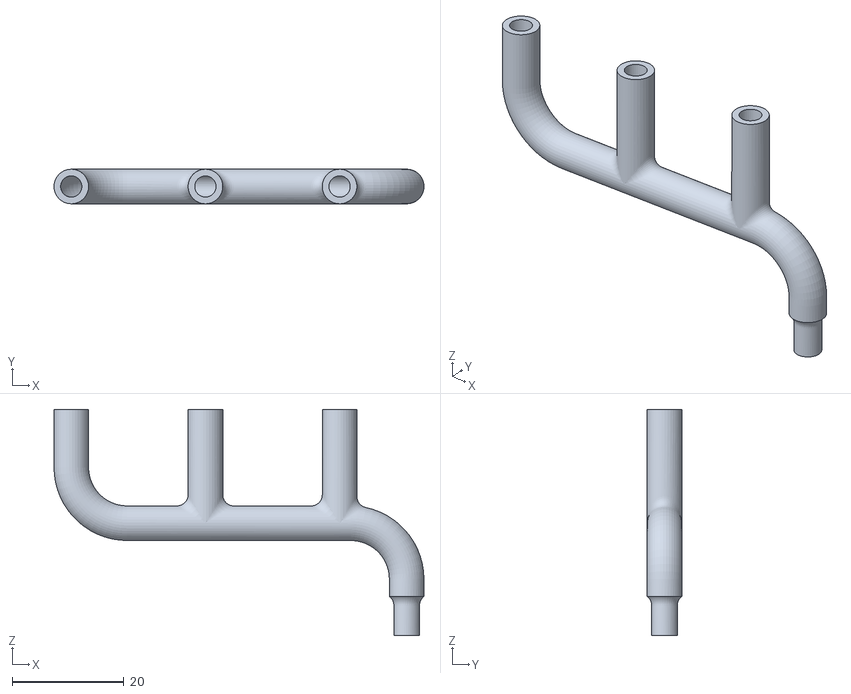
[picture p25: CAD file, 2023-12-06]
docs/Fall2023/cadFiles/Fall23_UpdatedManifold.STL
66.2 x 6.20 x 40.5

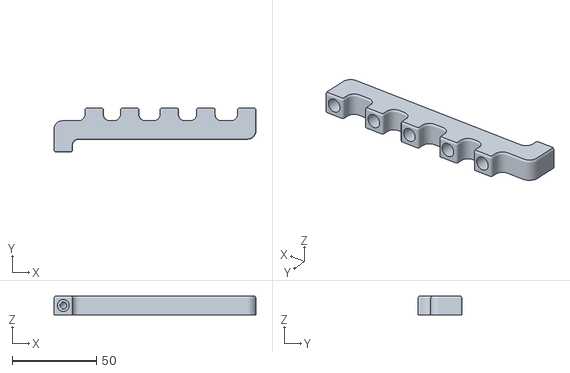
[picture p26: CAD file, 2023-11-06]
docs/hardware/spring2023/stlFiles/Manifold.STL
119.8 x 26.0 x 11.0

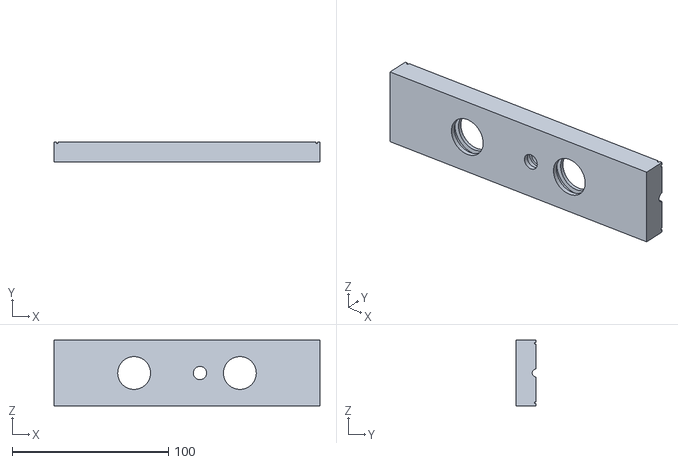
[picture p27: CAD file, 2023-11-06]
docs/hardware/spring2023/stlFiles/Chamber Bottom Plate.STL
170.0 x 13.0 x 42.0

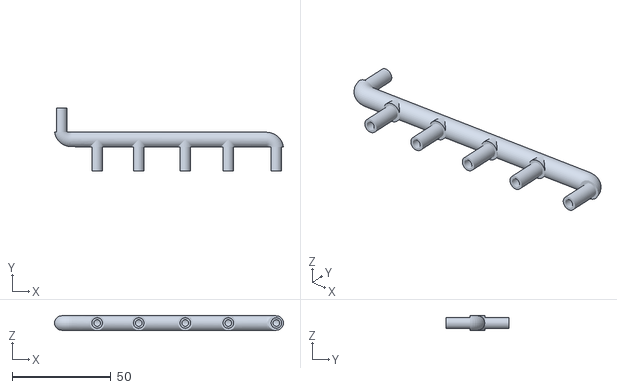
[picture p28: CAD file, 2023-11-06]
docs/hardware/spring2023/stlFiles/Soil Sensor Project Air Manifold.STL
115.7 x 32.0 x 7.35

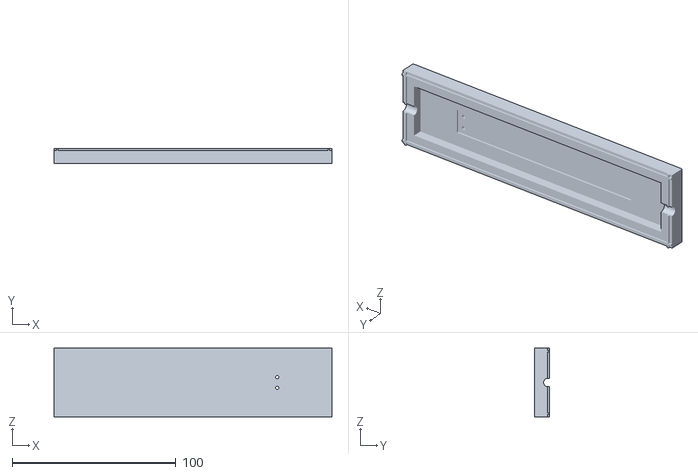
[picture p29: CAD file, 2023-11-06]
docs/hardware/spring2023/stlFiles/Chamber Top Plate.STL
170.0 x 9.00 x 42.0

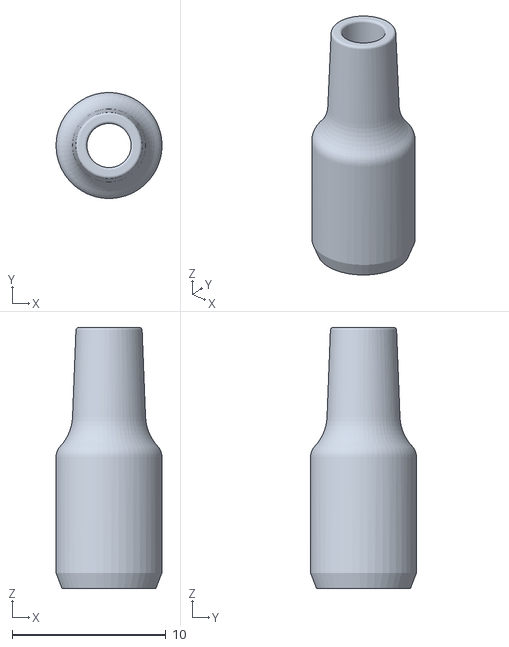
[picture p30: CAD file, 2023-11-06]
docs/hardware/spring2023/stlFiles/Manifold_End_Plug.STL
6.90 x 6.90 x 17.0

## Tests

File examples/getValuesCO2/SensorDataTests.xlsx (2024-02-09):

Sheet: SensorDataTests11_13_2023
Time(ms) | CO2(ppm) | Time (s) | Included test data from a "cold start" of the sensor | https://github.com/bellahenkel/Soil-Sensing-Device/commit/ae33c9672c6a8aa79bd54bf2f43081303b3e1b27
67 | 1330.94 | 0.067
1083 | 1337.34 | 1.083
2095 | 1349.38 | 2.095
3106 | 1333.59 | 3.106
4116 | 1202.19 | 4.116
5128 | 1217.19 | 5.128
6139 | 1245.16 | 6.139
7149 | 1313.44 | 7.149
8161 | 1327.97 | 8.161
9172 | 1328.59 | 9.172
10182 | 1193.91 | 10.182
11194 | 1233.91 | 11.194
12206 | 1236.88 | 12.206
13217 | 1312.34 | 13.217
14227 | 1317.03 | 14.227
15239 | 1327.97 | 15.239
16250 | 1235.16 | 16.25
17260 | 1189.53 | 17.26
18272 | 1211.09 | 18.272
19283 | 1311.09 | 19.283
20295 | 1310.78 | 20.295
21305 | 1312.03 | 21.305
22317 | 1294.84 | 22.317
23328 | 1204.06 | 23.328
24338 | 1215.78 | 24.338
25350 | 1264.53 | 25.35
26361 | 1294.38 | 26.361
27373 | 1293.28 | 27.373
28383 | 1297.5 | 28.383
29394 | 1170.16 | 29.394
30406 | 1180.63 | 30.406
31418 | 1219.84 | 31.418
32428 | 1293.75 | 32.428
33439 | 1302.66 | 33.439
34451 | 1309.38 | 34.451
35463 | 1213.13 | 35.463
36472 | 1157.5 | 36.472
37484 | 1193.91 | 37.484
38496 | 1285.78 | 38.496
39505 | 1287.66 | 39.505
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

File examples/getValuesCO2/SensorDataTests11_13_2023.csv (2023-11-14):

Time(ms) | CO2(ppm)
67 | 1330.94
1083 | 1337.34
2095 | 1349.38
3106 | 1333.59
4116 | 1202.19
5128 | 1217.19
6139 | 1245.16
7149 | 1313.44
8161 | 1327.97
9172 | 1328.59
10182 | 1193.91
11194 | 1233.91
12206 | 1236.88
13217 | 1312.34
14227 | 1317.03
15239 | 1327.97
16250 | 1235.16
17260 | 1189.53
18272 | 1211.09
19283 | 1311.09
20295 | 1310.78
21305 | 1312.03
22317 | 1294.84
23328 | 1204.06
24338 | 1215.78
25350 | 1264.53
26361 | 1294.38
27373 | 1293.28
28383 | 1297.5
29394 | 1170.16
30406 | 1180.63
31418 | 1219.84
32428 | 1293.75
33439 | 1302.66
34451 | 1309.38
35463 | 1213.13
36472 | 1157.5
37484 | 1193.91
38496 | 1285.78
39505 | 1287.66
40517 | 1271.72
41529 | 1252.19
42541 | 1192.81
43550 | 1179.06
44562 | 1211.72
45574 | 1276.25
46585 | 1280.94
47595 | 1276.41
48607 | 1204.22
49618 | 1164.06
50628 | 1176.72
51640 | 1248.91
52652 | 1280.94
53663 | 1295.47
54673 | 1275.94
55685 | 1183.59
56696 | 1167.19
57708 | 1155
58718 | 1250.47
59729 | 1262.97
60741 | 1264.38
61751 | 1193.59
62763 | 1159.38
63774 | 1140.31
64786 | 1197.34
65796 | 1247.34
66807 | 1248.44
67819 | 1251.72
68831 | 1167.03
69840 | 1129.53
70852 | 1172.19
71864 | 1247.19
72876 | 1249.06
73885 | 1252.5
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

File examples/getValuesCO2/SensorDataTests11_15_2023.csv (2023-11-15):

Time(ms) | CO2(ppm)
67 | 833.75
1083 | 864.38
2093 | 879.22
3104 | 878.28
4116 | 874.53
5126 | 861.72
6137 | 856.25
7149 | 856.25
8159 | 846.41
9170 | 844.06
10182 | 845.78
11192 | 838.75
12204 | 843.75
13215 | 842.34
14225 | 836.25
15237 | 835.16
16248 | 825.47
17258 | 821.56
18270 | 821.25
19281 | 833.59
20291 | 838.44
21303 | 839.84
22315 | 815.31
23324 | 807.19
24336 | 799.06
25348 | 798.59
26357 | 798.28
27369 | 795.94
28381 | 810.31
29392 | 817.81
30402 | 810.31
31414 | 808.28
32425 | 800.94
33435 | 790.94
34447 | 776.88
35459 | 781.09
36468 | 783.44
37480 | 787.19
38492 | 784.22
39501 | 780.94
40513 | 776.09
41525 | 770.16
42534 | 766.56
43546 | 754.53
44558 | 764.69
45568 | 762.34
46579 | 765.31
47591 | 763.44
48601 | 757.97
49612 | 758.44
50624 | 720.47
51636 | 749.69
52645 | 750.31
53657 | 749.53
54669 | 747.97
55678 | 744.53
56690 | 737.5
57702 | 740.31
58712 | 737.81
59723 | 726.56
60735 | 740.16
61745 | 737.34
62756 | 733.28
63768 | 729.06
64778 | 724.22
65789 | 714.22
66801 | 715.47
67811 | 726.41
68823 | 721.25
69834 | 724.69
70846 | 721.25
71856 | 713.75
72867 | 701.25
73879 | 711.25
74889 | 712.97
75900 | 698.28
76912 | 717.34
77922 | 723.75
78934 | 712.97
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

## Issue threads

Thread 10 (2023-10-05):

clean up code for CO2 sensor

bellahenkel, 2023-10-05:
There are fragments of code in the current CO2-sensor file that are not really doing anything. I need to go through it one more time and see if I can simplify it into only its required components.

bellahenkel, 2023-10-24:
Completed and pulled to main

Closed 2023-10-24.

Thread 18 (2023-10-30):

Restructure for compatibility with ArduinoIDE & PlatformIO

aufdenkampe, 2023-10-30:
Arduino IDE and PlatformIO both have specific requirements the structure of a library, so that sketches and other source files are properly compiled.

The [Arduino IDE and PlatformIO Part 1: How to structure a project to be compiled by both](https://insigh.io/blog/how-to-structure-a-project-to-be-compilable-by-arduino-ide-and-platformio-part-1/) blog post describes why putting header and source files in the `src` directory and `.ino` sketches in the `examples` directory is necessary. They provide the following example project as a summary:

```
senseAndUpload/
├── examples/
|   ├── exampleWifi/
|   │   └── exampleWifi.ino
|   └── exampleNBIoT/
|       └── exampleNBIoT.ino
└── src/
  ├── device/
  |   └── sensor.h
  └── networking/
      ├── nbiot.h
      └── wifi.h
```

NOTE that as we move or rename files, it is important to use the `git mv` command to preserve git history. For details and examples, see https://www.educative.io/answers/how-to-rename-or-move-files-in-git.

aufdenkampe, 2023-10-30:
A suggested structure for this project might be:

```
senseAndUpload/
├── examples/
|   ├── getValuesCO2/
|   │   └── getValuesCO2
|   └── getValuesModularSensors/
|       └── getValuesModularSensors.ino
|   └── runSoilDevice/
|       └── runSoilDevice.ino
└── src/
  ├── main.h
  ├── sensors/
  |   ├── co2_sensor.h
  |   └── co2_sensor.cpp
  └── soilDevice/
      ├── soilDevice.h
      └── soilDevice.cpp

```

aufdenkampe, 2023-10-30:
Maybe model a little bit like https://github.com/EnviroDIY/KellerModbus?
I'll look for another example.

aufdenkampe, 2023-11-10:
Completed with PR:
- #19

Closed 2023-11-10.

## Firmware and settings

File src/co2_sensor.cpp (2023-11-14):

/**
 * co2_sensor.cpp
 */

#include "co2_sensor.h"


//----------------------------------------------------------------------------
//                          PUBLIC SENSOR FUNCTIONS
//----------------------------------------------------------------------------

// Sets up functions
bool AlphasenseCO2::begin() {
    Serial.println("Initializing Alphasense IRC-A1 CO2 sensor");

    // Set the gain for the ADC
    ads.setGain(GAIN_ONE); // 1x gain +/- 4.096V 1 bit = 2mV 0.125mV
    Serial.println("Gain set.");

    // Check if the ADC is operational
    Serial.print("Checking ADC... ");
    if (!ads.begin(ADS1115_ADDRESS)) {
        Serial.println("Failed to initialize ADS.");
        return false;
    }

    Serial.println("ADC initialized successfully.");
    return true;
}


// Function to convert digital value from sensor ADC to CO2 reading in ppm
float AlphasenseCO2::getCO2PPM(void) {
    // Measure the voltage difference across two pins from the CO2 sensor
    int16_t results = ads.readADC_Differential_2_3();

    // Convert digital CO2 value to voltage (V)
    float CO2Voltage = ads.computeVolts(results);

    // Convert voltage to current (mA) - assuming a 250 Ohm resistor is in series
    float CO2Current = (CO2Voltage / 250) * 1000;

    // Convert current to ppm (using a formula recommended by the sensor manufacturer)
    float CO2PPM = 312.5 * CO2Current - 1250;

    return CO2PPM;
}

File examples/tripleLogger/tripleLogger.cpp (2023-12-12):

/** =========================================================================
 * triple_logger.cpp
 * Example logging gas readings from three soil depths along with temperature, humidity, and Mayfly stats
 *
 * Heavily based on the double_logger example created by Sara Geleskie Damiano <sdamiano@stroudcenter.org> in EnviroDIY/ModularSensors
 * @copyright (c) 2017-2022 Stroud Water Research Center (SWRC)
 *                          and the EnviroDIY Development Team
 *            This example is published under the BSD-3 license.
 *
 * Build Environment: Visual Studios Code with PlatformIO
 * Hardware Platform: EnviroDIY Mayfly Arduino Datalogger
 *
 * DISCLAIMER:
 * THIS CODE IS PROVIDED "AS IS" - NO WARRANTY IS GIVEN.
 * ======================================================================= */

// ==========================================================================
//  Defines for TinyGSM
// ==========================================================================
/** Start [defines] */
#ifndef TINY_GSM_RX_BUFFER
#define TINY_GSM_RX_BUFFER 64
#endif
#ifndef TINY_GSM_YIELD_MS
#define TINY_GSM_YIELD_MS 2
#endif
/** End [defines] */

// ==========================================================================
//  Include the libraries required for any data logger
// ==========================================================================
/** Start [includes] */
// The Arduino library is needed for every Arduino program.
#include <Arduino.h>

// EnableInterrupt is used by ModularSensors for external and pin change
// interrupts and must be explicitly included in the main program.
#include <EnableInterrupt.h>

// Include the main header for ModularSensors
#include <ModularSensors.h>
/** End [includes] */


// ==========================================================================
//  Data Logging Options
// ==========================================================================
/** Start [logging_options] */
// The name of this program file
const char* sketchName = "soil_sensor_device.cpp";
// Logger ID - we're only using one logger ID for both "loggers"
const char* LoggerID = "";
// The TWO filenames for the different logging intervals
const char* FileName10cm = "Logger_10cmDepth.csv";
const char* FileName20cm = "Logger_20cmDepth.csv";
const char* FileName50cm = "Logger_50cmDepth.csv";
const char* FileNameTempStats = "Logger_TempStats.csv";
// Your logger's timezone.
const int8_t timeZone = -6;  // Eastern Standard Time
// NOTE:  Daylight savings time will not be applied!  Please use standard time!

// Set the input and output pins for the logger
// NOTE:  Use -1 for pins that do not apply
const int32_t serialBaud = 115200;  // Baud rate for debugging
const int8_t  greenLED   = 8;       // Pin for the green LED
const int8_t  redLED     = 9;       // Pin for the red LED
const int8_t  buttonPin  = 21;      // Pin for debugging mode (ie, button pin)
const int8_t  wakePin    = 31;  // MCU interrupt/alarm pin to wake from sleep
// Mayfly 0.x D31 = A7
// Set the wake pin to -1 if you do not want the main processor to sleep.
// In a SAMD system where you are using the built-in rtc, set wakePin to 1
const int8_t sdCardPwrPin   = -1;  // MCU SD card power pin
const int8_t sdCardSSPin    = 12;  // SD card chip select/slave select pin
const int8_t sensorPowerPin = 22;  // MCU pin controlling main sensor power
/** End [logging_options] */


// ==========================================================================
//  Wifi/Cellular Modem Options
// ==========================================================================
/** Start [xbee_wifi] */
// For the Digi Wifi XBee (S6B)
#include <modems/DigiXBeeWifi.h>
// Create a reference to the serial port for the modem

HardwareSerial& modemSerial = Serial1;  // Use hardware serial if possible
const int32_t   modemBaud   = 9600;     // All XBee's use 9600 by default

// Modem Pins - Describe the physical pin connection of your modem to your board
// NOTE:  Use -1 for pins that do not apply
const int8_t modemVccPin    = -2;    // MCU pin controlling modem power
const int8_t modemStatusPin = 19;    // MCU pin used to read modem status
const bool useCTSforStatus  = true;  // Flag to use the modem CTS pin for status
const int8_t modemResetPin  = 20;    // MCU pin connected to modem reset pin
const int8_t modemSleepRqPin = 23;   // MCU pin for modem sleep/wake request
const int8_t modemLEDPin = redLED;   // MCU pin connected an LED to show modem
                                     // status (-1 if unconnected)

// Network connection information
const char* wifiId  = "xxxxx";  // WiFi access point, unnecessary for GPRS
const char* wifiPwd = "xxxxx";  // WiFi password, unnecessary for GPRS

DigiXBeeWifi modemXBWF(&modemSerial, modemVccPin, modemStatusPin,
                       useCTSforStatus, modemResetPin, modemSleepRqPin, wifiId,
                       wifiPwd);
// Create an extra reference to the modem by a generic name
DigiXBeeWifi modem = modemXBWF;
/** End [xbee_wifi] */


// ==========================================================================
//  Using the Processor as a Sensor
// ==========================================================================
/** Start [processor_sensor] */
#include <sensors/ProcessorStats.h>

// Create the main processor chip "sensor" - for general metadata
//IMPORTANT!!! Make sure to set the correct Mafly board version, or nothing will work correctly
//const char*    mcuBoardVersion = "v1.1";
const char* mcuBoardVersion = "v0.5b";
ProcessorStats mcuBoard(mcuBoardVersion);
/** End [processor_sensor] */


// ==========================================================================
//  Maxim DS3231 RTC (Real Time Clock)
// ==========================================================================
/** Start [ds3231] */
#include <sensors/MaximDS3231.h>

// Create a DS3231 sensor object
MaximDS3231 ds3231(1);
/** End [ds3231] */


  // ==========================================================================
  //    Maxim DS18 One Wire Temperature Sensor
  // ==========================================================================
  #include <sensors/MaximDS18.h>

  // OneWire Address [array of 8 hex characters]
  // If only using a single sensor on the OneWire bus, you may omit the address
  // DeviceAddress OneWireAddress1 = {0x28, 0xFF, 0xBD, 0xBA, 0x81, 0x16, 0x03, 0x0C};
  const int8_t OneWirePower = sensorPowerPin;  // Pin to switch power on and off (-1 if unconnected)
  const int8_t OneWireBus = 11;  // Pin attached to the OneWire Bus (-1 if unconnected) (D24 = A0)

  // Create a Maxim DS18 sensor objects (use this form for a known address)
  // MaximDS18 ds18(OneWireAddress1, OneWirePower, OneWireBus);

  // Create a Maxim DS18 sensor object (use this form for a single sensor on bus with an unknown address)
  MaximDS18 ds18(OneWirePower, OneWireBus);

// ==========================================================================
//  Bosch BME280 Environmental Sensor
// ==========================================================================
/** Start [bme280] */
#include <sensors/BoschBME280.h>

const int8_t I2CPower    = sensorPowerPin;  // Power pin (-1 if unconnected)
uint8_t      BMEi2c_addr = 0x76;
// The BME280 can be addressed either as 0x77 (Adafruit default) or 0x76 (Grove
// default) Either can be physically mofidied for the other address

// Create a Bosch BME280 sensor object
BoschBME280 bme280(I2CPower, BMEi2c_addr);
/** End [bme280] */


// ==========================================================================
//  Solenoid/Pump Gas Collector Sequence
// ==========================================================================

#include "CollectSample.h"

const int FLUSH_TIME = 10000;
const int MEASUREMENT_TIME = 3000;

// Set Valve pin
const int pump_pin = 7;

// Mayfly pins connected to control respective solenoids relays.
const int solenoid_pins[] = {4, 5, 6};

CollectSample collector;


// ==========================================================================
//  Alphasense IRC-A1 Nondispersive Infrared (NDIR) Carbon Dioxide (CO2) sensor
// ==========================================================================
/** Start [alphasense_co2] */
#include <sensors/AlphasenseCO2.h>

// NOTE: Use -1 for any pins that don't apply or aren't being used.
const int8_t AlphasenseCO2Power    = sensorPowerPin;  // Power pin
const uint8_t AlphasenseCO2ADSi2c_addr = 0x48;  // The I2C address of the ADS1115 ADC
const uint8_t AlphasenseCO2NumberReadings = 28;  // The number of readings to average


// Create an Atlas Scientific CO2 sensor object
// AtlasScientificCO2 atlasCO2(AlphasenseCO2Power, AlphasenseCO2ADSi2c_addr);
AlphasenseCO2 alphasenseCO2(AlphasenseCO2Power, AlphasenseCO2ADSi2c_addr,
                            AlphasenseCO2NumberReadings);

// Create concentration and temperature variable pointers for the EZO-CO2
Variable* alphasenseCO2CO2 = new AlphasenseCO2_CO2(
    &alphasenseCO2, "12345678-abcd-1234-ef00-1234567890ab");
Variable* alphasenseCO2voltage = new AlphasenseCO2_Voltage(
    &alphasenseCO2, "12345678-abcd-1234-ef00-1234567890ab");
/** End [alphasense_co2] */


// ==========================================================================
//  Creating the Variable Array[s] and Filling with Variable Objects
// ==========================================================================
/** Start [variable_arrays] */
// The variables to record gas measurements from the soil
Variable* variableList_gasMeasurement[] = {
                                    new AlphasenseCO2_CO2(&alphasenseCO2),
                                    new AlphasenseCO2_Voltage(&alphasenseCO2)
                                    };
// Count up the number of pointers in the gas measurement array
int variableCountGasMeasurement = sizeof(variableList_gasMeasurement) /
    sizeof(variableList_gasMeasurement[0]);
// Create the gas measruement VariableArray object
VariableArray arrayGasMeasurement;

// The variables to record temperature (and humidity and pressure) readings from the air
Variable* variableList_tempStats[] = {
                                    new MaximDS18_Temp(&ds18),
                                    new MaximDS3231_Temp(&ds3231),

                                    new BoschBME280_Temp(&bme280),
                                    new BoschBME280_Humidity(&bme280),
                                    new BoschBME280_Pressure(&bme280),
                                    new BoschBME280_Altitude(&bme280),

                                    new ProcessorStats_Battery(&mcuBoard),
                                    new ProcessorStats_FreeRam(&mcuBoard)
                                  };
// Count up the number of pointers in the temperature array
int variableCountTempStats = sizeof(variableList_tempStats) /
    sizeof(variableList_tempStats[0]);
// Create the temperature VariableArray object
VariableArray arrayTempStats;

/** End [variable_arrays] */


// ==========================================================================
//  The Logger Object[s]
// ==========================================================================
/** Start [loggers] */
// Create the 10cm soil depth logger instance
Logger logger10cm;

// Create the 20cm soil depth logger instance
Logger logger20cm;

// Create 50cm soil depth logger instance
Logger logger50cm;

//Create Mayfly Stats/Temperature logger instance
Logger loggerTempStats;
/** End [loggers] */

// ==========================================================================
//  Working Functions
// ==========================================================================
/** Start [working_functions] */
// Flashes the LED's on the primary board
void greenredflash(uint8_t numFlash = 4, uint8_t rate = 75) {
    for (uint8_t i = 0; i < numFlash; i++) {
        digitalWrite(greenLED, HIGH);
        digitalWrite(redLED, LOW);
        delay(rate);
        digitalWrite(greenLED, LOW);
        digitalWrite(redLED, HIGH);
        delay(rate);
    }
    digitalWrite(redLED, LOW);
}
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
void loop() {
    // Check if the current time is an even interval of the logging interval
    // For whichever logger we call first, use the checkInterval() function.
    if (logger10cm.checkInterval()) {
        // Print a line to show new reading
        Serial.println(F("--------------------->10<---------------------"));
        // Turn on the LED to show we're taking a reading
        digitalWrite(greenLED, HIGH);

        // Send power to all of the sensors (do this directly on the
        // VariableArray)
        Serial.print(F("Powering sensors...\n"));
        arrayGasMeasurement.sensorsPowerUp();
        logger10cm.watchDogTimer.resetWatchDog();
        // Wake up all of the sensors (do this directly on the VariableArray)
        Serial.print(F("Waking sensors...\n"));
        arrayGasMeasurement.sensorsWake();
        logger10cm.watchDogTimer.resetWatchDog();

        // Retrieve gas sample from the first soil depth (10cm)
        collector.getSample(0);
       
        // Update the values from all attached sensors (do this directly on the
        // VariableArray)
        Serial.print(F("Updating sensor values...\n"));
        arrayGasMeasurement.updateAllSensors();
        logger10cm.watchDogTimer.resetWatchDog();
        // Put sensors to sleep (do this directly on the VariableArray)
        Serial.print(F("Putting sensors back to sleep...\n"));
        arrayGasMeasurement.sensorsSleep();
        logger10cm.watchDogTimer.resetWatchDog();
        // Cut sensor power (do this directly on the VariableArray)
        Serial.print(F("Cutting sensor power...\n"));
        arrayGasMeasurement.sensorsPowerDown();
        logger10cm.watchDogTimer.resetWatchDog();

        // Stream the csv data to the SD card
        logger10cm.turnOnSDcard(true);
        logger10cm.logToSD();
        logger10cm.turnOffSDcard(true);
        logger10cm.watchDogTimer.resetWatchDog();

        // Turn off the LED
        digitalWrite(greenLED, LOW);
        // Print a line to show reading ended
        Serial.println(F("---------------------<10>---------------------\n"));
    }
    // Check if the already marked time is an even interval of the logging
    // interval For logger[s] other than the first one, use the
    // checkMarkedInterval() function.
    if (logger20cm.checkMarkedInterval()) {
        // Print a line to show new reading
        Serial.println(F("--------------------->20<---------------------"));
        // Turn on the LED to show we're taking a reading
        digitalWrite(redLED, HIGH);

        // Send power to all of the sensors (do this directly on the
        // VariableArray)
        Serial.print(F("Powering sensors...\n"));
        arrayGasMeasurement.sensorsPowerUp();
        logger10cm.watchDogTimer.resetWatchDog();
        // Wake up all of the sensors (do this directly on the VariableArray)
        Serial.print(F("Waking sensors...\n"));
        arrayGasMeasurement.sensorsWake();
        logger10cm.watchDogTimer.resetWatchDog();


        // Retrieve gas sample from the second soil depth (20cm)
        collector.getSample(1);

        // Update the values from all attached sensors (do this directly on the
        // VariableArray)
        Serial.print(F("Updating sensor values...\n"));
        arrayGasMeasurement.updateAllSensors();
        logger10cm.watchDogTimer.resetWatchDog();
        // Put sensors to sleep (do this directly on the VariableArray)
        Serial.print(F("Putting sensors back to sleep...\n"));
        arrayGasMeasurement.sensorsSleep();
        logger10cm.watchDogTimer.resetWatchDog();
        // Cut sensor power (do this directly on the VariableArray)
        Serial.print(F("Cutting sensor power...\n"));
        arrayGasMeasurement.sensorsPowerDown();
        logger10cm.watchDogTimer.resetWatchDog();

        // Stream the csv data to the SD card
        logger20cm.turnOnSDcard(true);
        logger20cm.logToSD();
        logger20cm.turnOffSDcard(true);
        logger10cm.watchDogTimer.resetWatchDog();

        // Turn off the LED
        digitalWrite(redLED, LOW);
        // Print a line to show reading ended
        Serial.println(F("--------------------<20>---------------------\n"));
    }


    // Check if the already marked time is an even interval of the logging
    // interval For logger[s] other than the first one, use the
    // checkMarkedInterval() function.
    if (logger50cm.checkMarkedInterval()) {
        // Print a line to show new reading
        Serial.println(F("--------------------->50<---------------------"));
        // Turn on the LED to show we're taking a reading
        digitalWrite(redLED, HIGH);

        // Send power to all of the sensors (do this directly on the
        // VariableArray)
        Serial.print(F("Powering sensors...\n"));
        arrayGasMeasurement.sensorsPowerUp();
        logger10cm.watchDogTimer.resetWatchDog();
        // Wake up all of the sensors (do this directly on the VariableArray)
        Serial.print(F("Waking sensors...\n"));
        arrayGasMeasurement.sensorsWake();
        logger10cm.watchDogTimer.resetWatchDog();

        collector.getSample(2);
        // Update the values from all attached sensors (do this directly on the
        // VariableArray)
        Serial.print(F("Updating sensor values...\n"));
        arrayGasMeasurement.updateAllSensors();
        logger10cm.watchDogTimer.resetWatchDog();
        // Put sensors to sleep (do this directly on the VariableArray)
        Serial.print(F("Putting sensors back to sleep...\n"));
        arrayGasMeasurement.sensorsSleep();
        logger10cm.watchDogTimer.resetWatchDog();
        // Cut sensor power (do this directly on the VariableArray)
        Serial.print(F("Cutting sensor power...\n"));
        arrayGasMeasurement.sensorsPowerDown();
        logger10cm.watchDogTimer.resetWatchDog();

        // Stream the csv data to the SD card
        logger50cm.turnOnSDcard(true);
        logger50cm.logToSD();
        logger50cm.turnOffSDcard(true);
        logger10cm.watchDogTimer.resetWatchDog();
        
        // Turn off the LED
        digitalWrite(redLED, LOW);
        // Print a line to show reading ended
        Serial.println(F("--------------------<50>---------------------\n"));
    }

    // Check if the already marked time is an even interval of the logging
    // interval For logger[s] other than the first one, use the
    // checkMarkedInterval() function.

     if (loggerTempStats.checkMarkedInterval()) {
        // Print a line to show new reading
        Serial.println(F("--------------------->Temp_MayflyStats<---------------------"));
        // Turn on the LED to show we're taking a reading
        digitalWrite(redLED, HIGH);

        // Send power to all of the sensors (do this directly on the
        // VariableArray)
        Serial.print(F("Powering sensors...\n"));
        arrayTempStats.sensorsPowerUp();
        logger10cm.watchDogTimer.resetWatchDog();
        // Wake up all of the sensors (do this directly on the VariableArray)
        Serial.print(F("Waking sensors...\n"));
        arrayTempStats.sensorsWake();
        logger10cm.watchDogTimer.resetWatchDog();

        // Update the values from all attached sensors (do this directly on the
        // VariableArray)
        Serial.print(F("Updating sensor values...\n"));
        arrayTempStats.updateAllSensors();
        logger10cm.watchDogTimer.resetWatchDog();
        // Put sensors to sleep (do this directly on the VariableArray)
        Serial.print(F("Putting sensors back to sleep...\n"));
        arrayTempStats.sensorsSleep();
        logger10cm.watchDogTimer.resetWatchDog();
        // Cut sensor power (do this directly on the VariableArray)
        Serial.print(F("Cutting sensor power...\n"));
        arrayTempStats.sensorsPowerDown();
        logger10cm.watchDogTimer.resetWatchDog();

        // Stream the csv data to the SD card
        loggerTempStats.turnOnSDcard(true);
        loggerTempStats.logToSD();
        loggerTempStats.turnOffSDcard(true);
        logger10cm.watchDogTimer.resetWatchDog();

        // Turn off the LED
        digitalWrite(redLED, LOW);
        // Print a line to show reading ended
        Serial.println(F("--------------------<Temp_MayflyStat>---------------------\n"));
    }

    // Once a day, at noon, sync the clock
    if (Logger::markedLocalEpochTime % 86400 == 43200) {
        // Turn on the modem
        modem.modemWake();
        // Connect to the network
        if (modem.connectInternet()) {
            // Synchronize the RTC
            logger10cm.setRTClock(modem.getNISTTime());
            // Disconnect from the network
            modem.disconnectInternet();
        }
        // Turn off the modem
        modem.modemSleepPowerDown();
    }
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

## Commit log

2023-10-02 Code for CO2 Sensor
    Code that isolates the processes required to operate the CO2 sensor
2023-10-02 CO2 Sensor Code
    Code for the CO2 Sensor
2023-10-04 Solenoid and Pump Programming
2023-10-05 Revised main code
    Revised code from Soil_Program. Controls functions for the solenoid valves, pump, and CO2 sensor. Still needs to be cleaned up some.
2023-10-24 Update co2_sensor.cpp
    This is the updated CO2 sensor code. Updates include:
    -I cleaned it up quite a bit and added some comments for readability.
    -updated the formula used to convert the voltage drop from the sensor to ppm of CO2. It should be more accurate with this newer formula.
    -CO2 data now saves to the SD card with timestamp.
2023-10-29 Update platformio.ini
    Removes some libraries from .ini file that are no longer needed in the updated co2-sensor.cpp code.
2023-11-01 Reorganization of File Tree Structure
    [Chamber Bottom Plate.STL, Chamber Top Plate.STL, Manifold.STL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]
2023-11-01 Create docs folder
    Moved several resources, electrical schematics, and design documents created by previous project teams into a newly created docs folder per #18
    [Chamber Bottom Plate.STL, Chamber Top Plate.STL, Manifold.STL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]
2023-11-07 Create ALPHASENSE_IRC_A1.h for CO2 sensor
    creates header file for the CO2 sensor. Modified code from the AnalogElectricalConductivity sensor from ModularSensors. This code does not work as intended.
2023-11-07 Create ALPHASENSE_IRC_A1.cpp
    This contains the functions needed for the CO2 sensor to get readings. Currently, this does not work correctly with the ALPHASENSE_IRC_A1.h file.
2023-11-08 Fixes to triple_logger, Add CollectSample
    Issues with the first two loggers not collecting data from some sensors was fixed.
    Added a CollectSample object which will eventually be called to operate the solenoids and pumps to take samples from the soil.
    Also copied over the correct .ini file based on the double_logger example.
    [co2_sensor.cpp, tripleLogger.cpp]
2023-11-13 Add Sensor Test Data
    Included test data from a "cold start" of the sensor
    [SensorDataTests11_13_2023.csv]
2023-11-15 11_15_2023SampleTest
    This is data from the sensor while is was left in a garbage bag full of outdoor air.
    [11_15_2023SensorDataTests.csv]
2023-11-17 Triple Logger Update - Collect Sample
    Created a class for the function that gets samples from a certain depth in the soil. It is now in its own header file ("CollectSample.h")
    Also changed some libraries in some older example files to reference from ModularSensors.
2023-11-17 Minor Changes for Testing
    Made a few changes to the SoilSensor test code so that team members can easily test their device.
2023-11-20 11-20-2023 Sensor Data (200ms)
    [11_20_2023SensorData_200ms.csv]
2023-11-22 Renaming src files for CO2 sensor
    `git mv src/co2_sensor.h src/AlphasenseIRCA1_CO2.h`
    `git mv src/co2_sensor.cpp src/AlphasenseIRCA1_CO2.cpp`
2023-11-22 Moved Alphasense to `src/sensors`
    Requires that sketches include subdirectory in includes, such as: `#include <sensors/AlphasenseIRCA1_CO2.h>`
2023-11-22 Add SensorDataTests plots
    [SensorDataTests.xlsx, SensorDataTests11_15_2023.csv, SensorDataTests11_20_2023_200ms.csv]
2023-11-27 Added Alphasense Sensor, General Clean-Up
    Added an Alphasense Sensor instance using the new code provided by ModularSensors. Also did some general code/comment clean-up to enhance readability. Appears to compile, but have not had time to tes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
2023-11-30 tripleLogger Reformatting, Added Comments
    Added a forth logger that tracks temperature, humidity, and Mayfly stats (basically, anything that is not soil gas data).
    Changed/added some comments for relevance and general readability.
    I'm now having to work with an older version of the Mayfly board, so another line was added at 120 to make it easy to switch between board versions.
    This update has been tested, and appears to work as expected with all the listed sensors.
2023-12-06 adding .STL file for soil manifold
    . Instructions for design and printing inside the "Tate_SoildWorks_DLA" PDF file
    [Fall23_UpdatedManifold.STL]
2023-12-07 include .ino file (for Arduino IDE use)
